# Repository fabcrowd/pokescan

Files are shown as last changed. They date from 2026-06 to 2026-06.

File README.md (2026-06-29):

# Card Scanner Stand — iPhone 16 Pro + Toybox

A **plastic-modular copy stand on a single wood-dowel spine** for scanning trading cards (Pokémon, MTG, sports, etc.) with a phone camera app (Delver, ManaBox, Collectr, etc.). Everything prints and slide-fits together (no screws); one 8 mm wood dowel is the only wood part, and pulling it flat-packs the whole stand.

The design targets two hard constraints that generic MakerWorld/Thingiverse stands ignore:

1. **Toybox Alpha 3 build volume** — **70 × 80 × 90 mm** (script uses conservative **68 × 78 × 88** usable). Large parts **split** with sliding dovetails (sides) + tongue-and-groove (bottom).
2. **iPhone 16 Pro optics** — the main (Fusion) wide camera has a large minimum focus distance and a **focus dead zone**; the LED torch sits on-axis next to the lens and creates **holo/foil glare** unless the light path is shaped.

---

## Current recommended architecture

**Plastic-modular column** on one **8 mm wood dowel** + **adjustable cam-lever phone head** + **rotating cross-polarizer** + **flow-through card lane** (Phase-2 feeder ready). Every part fits the Toybox bed; slide-fit joints, no screws.

| Part | Material | Role |
|---|---|---|
| `base_left/right.stl` | Print ×1 each | Split ballast base (120×72 mm assembled); dovetail + T&G joinery |
| `column_segment.stl` ×3 | Print | 34×34 posts; boss/recess slide-nest; vertical dowel bore |
| `head_post.stl` | Print | Scaled runway + **D-index flat** (rotation key) |
| `head_clamp.stl` | Print | Bilateral split collar; shelf pins + scale pointer |
| `cam_lever.stl` + `clamp_pin.stl` | Print | Flip-down eccentric lever |
| `phone_shelf_left/right.stl` | Print ×1 each | Split shelf (68×68 mm assembled); camera opening toward card |
| `torch_deflector.stl` | Print | Off-axis baffle (**black** PLA) |
| `polarizer_base.stl` + `polarizer_dial.stl` | Print | Rotating lens polarizer (**black** base) |
| `card_lane_left/right.stl` | Print ×1 each | Gravity ramp → flat scan nest; magazine dock rails + latch notch |
| `card_magazine_left/right.stl` | Print ×3 sets | Modular card magazine cartridge halves (snap-in, gravity feed) |
| `card_magazine_lid.stl` | Print ×6 | Snap-on lid per half (keeps stack aligned during transport) |
| `nest_frame.stl` | Print ×1 | Phase-2a scan deck frame with U-channels |
| `nest_tray_ramp.stl` / `nest_tray_bin.stl` | Print ×1 each | Phase-2a slide-out tray halves (butt-join at centre) |
| `nest_stop.stl` | Print ×1 | Phase-2a hard return stop tab |
| 8 mm dowel | Wood (only wood part) | Spine through base → segments → head_post socket |

```
Side view (conceptual)

  ┌─────────────── iPhone 16 Pro (camera down)
  │   [polarizer dial rotates] + torch deflector cartridge
  ╞═══════════════ phone_shelf (on head_clamp pins)
 ┌┴┐ head_clamp ← slides on head_post scale; cam_lever locks
 │ ║ ║ head_post runway (55 mm travel, engraved ticks)
 │ ║ ║
 │ ║ ║ ← 8 mm wood dowel
 │ ║ ║   column_segment ×3
 ┌┴─╨─┴┐ base              card_lane: hopper lip ↘ ramp ↘ scan nest (z0) ↘ bin step
 └─────┘                   [horn slot — Phase-2a gate linkage; see docs/phase-2a-manual-feeder.md]
  Lens 296–331 mm (3 segments, clamp range) — ≥260 mm ✓
  verify_assembly() checks lens XY over scan nest (≤2 mm)
```

---

## CS30 Arch v13 — Integrated Phone Arch + Gravity Ramp (current)

`design/cs30_arch.py` — a **Card Slinger 3.0-inspired arch** that wraps the `photo_box` light enclosure. Five printable parts (black PLA), two M3 bolts, two M3 hex nuts. No wood. No separate mount needed — the arch legs stand on the table with wide foot plates that abut the photo_box walls for lateral location.

```
Side view

  ┌───────────────────────── phone bridge (two halves, camera aperture 36×30mm)
  │    ←  dual sockets snap onto two carriage pegs (x=41mm + x=57mm)
  ╞═══════╤═════╤══════════ carriages lock with M3 knob (5mm rack pitch)
  │       │     │
  │       │     │  arch legs (2 sections each, 82mm+82mm = 164mm)
  │       │     │
  ╞═══════╧═════╧══════════ legs clip to photo_box left/right walls (8mm thick)
  [  photo_box v25 (84×44×44mm, LED-lit, white PLA)  ]
  ← gravity ramp clips to front end cap → cards slide to scan window →
```

### Part list and print settings (v13)

| STL | Qty | Bed dims | Orientation | Profile | Infill | Brim | Notes |
|-----|-----|---|---|---|---|---|---|
| `cs30_fit_test.stl` | 1 | 68×16×30mm | Flat (Z-up) | Recommended | 15% gyroid | None | **Print FIRST** (~18 min); validates (A) carriage-on-leg, (B) bridge peg, (C) ramp C-clip, **(D) M3 bolt/nut trap** |
| `cs30_ramp.stl` | 1 | 68×70.7×32.6mm | Flat (floor down) | Recommended | 15% gyroid | None | 20° gravity ramp; C-clip foot snaps onto photo_box front end cap (3mm); self-supporting |
| `cs30_arch_leg_section.stl` | **4** | **14×24×87mm** | Standing (Z-up, **foot plate down**) | Recommended | 20% gyroid | **NO** | 2 per leg, stack → 164mm; 24mm foot plate is bed face; corner notches clear photo_box end cap; inner face abuts wall; **no brim — 1mm bed margin** |
| `cs30_phone_bridge_half.stl` | **2** | 60×78×10mm | Flat (plate face down) | Better Quality | 20% gyroid | **NO** | 6mm plate; blind carriage sockets (5mm + 1mm floor); butt join at x=0; **no brim — 1mm bed margin** |
| `cs30_arch_carriage.stl` | **2** | 30×16×55mm | +Y face down (C-channel up) | Better Quality | 25% gyroid | ON | Slot 14.6×12.3mm clears rack teeth; nut trap 5.7mm; finer layers improve bore + slot |
| `cs30_lock_knob.stl` | **2** | 19.2×20×8mm | Flat (bottom face down) | Better Quality | 20% gyroid | None | **Top-face** socket (outer face when assembled) captures M3×30mm bolt head; six grip flats; indicator groove on top |

All parts: black PLA. 3 perimeter walls, 0.2mm layers. No supports.

### Hardware (v13)

| Item | Qty | Role |
|---|-----|---|
| M3×**30mm** socket-head bolt (ISO 4762) | 2× | Through carriage ±X; clamps leg — 30mm needed (25mm falls 2mm short of nut) |
| M3 hex nut | 2× | Drops into square nut trap on carriage +X face |

### Fit test procedure

Print `cs30_fit_test.stl` flat. Four features on one 68×16×30mm part:

| Feature | Test | Pass | Fail → adjust |
|---|---|---|---|
| **(A) Leg stub** (left, x=-22) | Slide printed carriage C-channel down over 14×10mm column | Slides freely, ~0.3mm play | `CARR_CL` 0.3→0.4mm, reprint |
| **(B) Peg base** (centre) | Press bridge half sockets over 3mm-radius pegs at ±8mm | Snaps on with light thumb pressure, no wobble | `SEC_PEG_CL` 0.3→0.35mm, reprint |
| **(C) End cap stub** (right, x=+21) | Press ramp C-clip foot over 3mm plate | Snaps with single push, stays held | `EC_SOCK_CL` 0.3→0.4mm, reprint |
| **(D) Nut trap stub** (far right, x=+30..39) | Thread M3×**30mm** bolt through 3.4mm hole; drop M3 hex nut into 5.7×5.7mm pocket | Bolt passes freely; nut drops flush with fingers | Bolt binds → `BOLT_D` 3.4→3.6mm; nut jams → `NUT_TRAP_CL` 0.2→0.35mm; reprint |

### Assembly sequence

See `docs/cs30_assembly.md` for the full 8-step guide. Quick overview:

1. Build photo_box (see `docs/photo_box_assembly.md`)
2. Drop M3 nut into each carriage trap; insert M3×30mm bolt from -X face, thread into nut; slide lock knob onto bolt head
3. Slide one carriage onto each leg section from the top
4. Stack two leg sections per side (male peg → female socket, press flush)
5. Stand each leg stack beside the photo_box left/right walls — foot plate (24mm wide) rests on table; inner x-face of foot abuts photo_box wall outer face for lateral location
6. Slide both carriages to the same rack tooth mark; tighten both knobs
7. Press both bridge halves down onto carriage pegs; halves meet at centreline
8. Snap ramp C-clip foot over photo_box front end cap (3mm body)

### Height adjustment

| Rack mark | Bridge height | Camera → card | Focus mode |
|---|---|---|---|
| 30mm | 85mm | **81mm (8.1cm)** | Ultra-wide macro ✓ |
| 50mm | 105mm | **101mm (10.1cm)** | Ultra-wide macro ✓ |
| 70mm | 125mm | **121mm (12.1cm)** | Ultra-wide macro ✓ **(recommended)** |
| 80mm | 135mm | **131mm (13.1cm)** | Ultra-wide macro ✓ |
| 85mm | 140mm | **136mm (13.6cm)** | Ultra-wide macro ✓ (safe limit) |
| 90mm | 145mm | **141mm (14.1cm)** | Ultra-wide macro (borderline — may switch lens) |
| 95mm | 150mm | **146mm (14.6cm)** | ⚠ Borderline — test before batch scanning |

Camera → card = bridge height − 4mm (card face at FLOOR_T=4mm above table). Bridge height = rack mark + 55mm (CARR_H=50 + SEC_PEG_H=5). Maximum physical rack mark = 114mm (column height 164mm − CARR_H 50mm). Dead zone for iPhone 16 Pro main camera begins around 14cm; ultra-wide macro covers 2cm–14cm.

**Recommended range: rack marks 30–85mm** — keeps camera-to-card under 136mm, safely within ultra-wide macro territory. At rack mark 90mm the camera-to-card distance is 141mm, which is borderline (iOS may auto-switch to the main lens). Rack mark 70mm (≈12cm) gives the best framing balance. Use 2× digital zoom in Apple Camera or Magnifier for tighter crops without moving closer.

Each tooth = 5mm. Loosen both knobs → slide to mark → tighten → recheck level.

> **App compatibility at macro range:** Apple Camera (auto-switches to ultra-wide macro below ~14cm) and Magnifier work at any rack mark. Third-party scanner apps (Delver Lens, ManaBox, Collectr) may stay on the main camera and blur — test at rack mark 50 before committing to a batch scan.

### Clearance reference (v13)

| Interface | Constant | Value |
|---|---|---|
| Carriage C-channel → leg | `CARR_CL` | 0.3mm/face |
| Bridge socket → carriage peg | `SEC_PEG_CL` | 0.3mm radius |
| Ramp C-clip → end cap body | `EC_SOCK_CL` | 0.3mm/face |
| M3 bolt clearance | `BOLT_D` | 3.4mm |

### Rebuild cs30_arch STLs

```bash
# AgentCAD (Claude Code):
#   mcp__agentcad__run("design/cs30_arch.py", "rebuild", params="PART=N")
#   PART=0 = assembly preview  1=ramp  2=leg_section  3=bridge_half  4=carriage  5=lock_knob

# Direct:
uvx --from build123d --with bd_warehouse python design/cs30_arch.py
# Set PART=N at top of script; STLs land in design/output/cs30_*.stl
```

### System verification

After changing any constant in `photo_box.py` or `cs30_arch.py`, run the constraint checker to confirm clearances, optics, and macro focus range are still valid:

```bash
py design/cs30_verify.py
```

19 checks across 6 categories (camera-to-card range, geometric clearances, aperture vignetting, LED channel depth, foot plate notch, bridge alignment). Exits 0 on pass, 1 on failure. Takes under 1 second — no build123d or AgentCAD required.

---

## CS2 — Card Scanner v2 (C-Stand + Hopper, Toybox-native)

`design/cs2_*.py` — a **Card Slinger 2-inspired vertical platform stand** with an open-top card hopper and a height-adjustable phone shelf. All parts fit the Toybox bed without modification. No wood. No arch structure. Card drops in face-up; phone rests on shelf above looking down through a 36×30 mm aperture.

```
Side view

  ┌──────────────────────────────────── iPhone 16 Pro (face down)
  │   camera aperture: 36×30mm
  ╞══════════════════════════════════ platform (68×75×8mm, adjustable)
  │                                    bolts to wall at 4 heights: 100/125/150/165mm
  │  ┌─────────────────────────┐
  │  │   wall column           │  97×14×174mm (2 sections × 2 halves)
  │  │   (black PLA, upright)  │
  │  └─────────────────────────┘
  [  hopper (97×72×50mm, 2 halves)  ]
     open-top card slot: 90×65mm
     card face at z=4mm (FLOOR_T)
```

### Part list (all black PLA unless noted)

| STL | Dims (mm) | Qty | Orientation | Notes |
|-----|---|-----|---|---|
| **`cs2_fit_test.stl`** | 64×38×20 | 1 | Flat | **Print FIRST** — validates peg fit + pol_clip aperture press-fit |
| `cs2_hopper_left.stl` | 48.5×72×70 | 1 | Upright | Left half of card hopper (v3, 70mm, ~160 cards); Phase 2 shaft holes + exit slot |
| `cs2_hopper_right.stl` | 48.5×72×70 | 1 | Upright | Right half |
| `cs2_platform.stl` | 68×75×8 | 1 | Flat | Phone shelf; Y-direction M3 bolt holes at x=±22mm |
| `cs2_wall_bot_left.stl` | 49.5×20×88 | 1 | Upright | Bottom-left wall section |
| `cs2_wall_bot_right.stl` | 49.5×20×88 | 1 | Upright | Bottom-right wall section |
| `cs2_wall_top_left.stl` | 49.5×14×88 | 1 | Upright | Top-left wall section |
| `cs2_wall_top_right.stl` | 49.5×14×88 | 1 | Upright | Top-right wall section |
| `cs2_peg.stl` | 10×10×10 | 1 plate | Flat | 4× 3mm alignment pegs; use 2 for hopper join (PETG preferred) |
| `cs2_pol_clip.stl` | 44×38×8 | 1 | Flat | **White PLA** — optional; polarizer film clip for aperture |
| `cs2_phone_pol.stl` | 44×38×3 | 1 | Flat | **White PLA** — optional; matched phone-camera polarizer frame |
| `cs2_diffuser.stl` | 68×75×1.5 | 1 | Flat + **brim** | **White PLA** — optional; torch scatter plate for diffuse fill light |

All parts: 3 perimeter walls, 0.2mm layers, 20% infill, no supports.

### Hardware BOM (per scanner)

| Item | Qty | Spec | Use |
|---|-----|---|-----|
| M3×30mm socket-head bolt | 8 | ISO 4762 | Platform-to-wall (2) + wall section joins (6) |
| M3×20mm socket-head bolt | 6 | ISO 4762 | Hopper half joins (2) + spare |
| M3 hex nut | 14 | standard | All bolt receivers |
| 3mm dowel pin | 2 | from `cs2_peg.stl` | Hopper seam alignment |
| CA glue | small tube | cyanoacrylate | Wall flange to hopper back face (Phase 1) |

### Fit test procedure

Print `cs2_fit_test.stl` flat — same PLA colour as target parts (pigment affects shrink).

| Feature | Test | Pass | Fail → adjust |
|---|---|---|---|
| **(A) Hole block** (left, x=−22) | Insert 3mm dowel (cut from `cs2_peg.stl`) into blind hole at z=14mm; thread M3×20mm bolt through at z=8mm | Dowel slides in with light thumb push; bolt passes freely | Dowel too tight → `PEG_D` in `cs2_peg.py` +0.05mm steps; reprint peg plate |
| **(B) Aperture ring** (right, x=+20) | Press `cs2_pol_clip` plug (35.6×29.6mm) into the 36×30mm opening from below | Firms up with thumb pressure; stays without adhesive | Too tight → `PLUG_W`/`PLUG_D` in `cs2_pol_clip.py` +0.1mm; too loose → −0.1mm; reprint clip |

### Assembly sequence

See **`docs/cs2_assembly.md`** for the full step-by-step guide including fit test procedure, accessory setup, and iPhone placement notes.

Quick reference:
1. **Join hopper halves:** align seam at x=0; insert 2× 3mm dowel pegs (front + back, z=17mm); thread 2× M3×20mm bolts at z=25mm.
2. **Build wall column:** join 4 sections into bot + top pairs (3× M3×30mm per seam); join left+right sides.
3. **Attach wall to hopper:** CA glue wall front face to hopper back face; hold 60 s.
4. **Mount platform:** M3×30mm bolts through platform back edge (Y-direction, x=±22mm, z=4mm from bottom); thread into wall; nut on wall back face.
5. **Scan:** card face-up in hopper; phone face-down on platform, camera over aperture.

> **Workflow speed:** drop a full load (≈120 cards, or ≈160 with the 70mm tall v3 hopper) through the centering insert (`cs2_centering_insert.stl`) — cards self-align in under a second. Scan + manual eject: ~900 cards/hour. With Phase-2 motorised eject and separator: ~600–900 cards/hour realistic. See `docs/workflow-speed.md` for the full capacity table and toss-and-scan steps.

### Height settings

| Platform position (mm) | Camera→card clearance | Notes |
|---|---|---|
| 100 | 104mm (10.4cm) | Ultra-wide macro ✓ |
| 125 | 129mm (12.9cm) | Ultra-wide macro ✓ **(recommended)** |
| 150 | 154mm (15.4cm) | Borderline macro — test before batch |
| 165 | 169mm (16.9cm) | Main camera territory |

Camera→card = platform Z + PLAT_T(8) − FLOOR_T(4). Ultra-wide macro range: 2cm–14cm.

### Lighting accessories (optional)

**Diffuser plate** (`cs2_diffuser.stl` — white PLA, 68×75×1.5mm): Lay flat on the platform top; phone rests on the diffuser. The phone torch hits the white PLA surface and scatters sideways into the hopper, converting the harsh point-source torch into broad soft-box fill light. The 36×30mm aperture cut-out aligns with the platform aperture exactly. Use brim in slicer — 1.5mm thin part at 68mm bed width warps without it.

**Cross-polarization** (`cs2_pol_clip.stl` + `cs2_phone_pol.stl` — holographic/foil cards only): Print both in white PLA. Cut two 30×24mm squares from a linear polarizing film sheet. Insert one square into each clip's recess. Rotate one square 90° relative to the other. Slip `cs2_pol_clip` into the platform aperture from below; hold `cs2_phone_pol` over the phone camera with a rubber band through the 4 corner holes. Kills specular glare on holo/foil surfaces.

**Recommended combinations:**
- Standard cards: diffuser plate only
- Holo/foil cards: diffuser plate + cross-pol pair

### Rebuild CS2 STLs

```bash
# Set PART=N at top of each script, then run via AgentCAD or directly:
uvx --from build123d python design/cs2_hopper.py   # PART=1 left / PART=2 right
uvx --from build123d python design/cs2_wall.py     # PART=1..4 for four sections
uvx --from build123d python design/cs2_platform.py # PART=0 single piece
```

### Verify CS2 geometry

```bash
py design/cs2_verify.py
```

31 checks: bed fit, card clearance, aperture alignment, platform height range, shaft hole clearance, wall coverage, bolt alignment, peg clearance. Exits 0 on pass.

---

## v2: Rack-Pinion Adjustable Stand *(superseded by CS30 Arch v5)*

`design/rack_stand_v2.py` — a **Card Slinger-inspired** stand with a rack-and-pinion height adjustment column. Eight printable parts (including one tolerance test block), two M3 bolts, and a rubber band. No wood required.

```
Card flow + camera geometry

  y = 0 mm  ← user inserts card here (tray_back funnel entry)
  y = 44 mm ← camera aims here  (card centre; tray split join)
  y = 88 mm ← back of tray / stand column base (STAND_Y = CARD_L)

  z-stack (lowest carriage position = 260 mm lens height):
    z=0        table
    z=0..13.5  card tray (tray_back y=0..44, tray_front y=44..88)
    z=13.5     foot bottom rests on tray wall tops (x = ±32..35 mm)
    z=13.5..45.5  stand foot body (70×50×32 mm)
    z=45.5..49.5  foot D-peg → rack section 1 socket
    z=45.5..285.5 rack column (3 × 80 mm sections)
    z=205.5+   phone carriage (section 3 minimum; slides on column, locked with M3 side-bolt)
    z=+CAR_H   phone platform (bolted to carriage with 2× M3×8)
    260..290 mm  lens height range (carriage adjustable within section 3) ✓
```

### Part list and print settings (v2)

| STL | Bed dims | Orientation | Profile | Infill | Qty | Notes |
|-----|---|---|---|---|-----|---|
| `rs2_fit_test.stl` | 42×38×20 mm | Flat (base down) | Recommended | 15% | 1× | **Print FIRST** (with knob) — verify all 5 features before main set |
| `rs2_rack_section.stl` | 26×26×84 mm | Standing (Z-up, teeth on +Y face) | **Better Quality** | 25% | 3× | Finer layers give cleaner tooth faces |
| `rs2_stand_foot.stl` | 70×50×36 mm | **Rotate 90° in slicer** — 70 mm along Y | Recommended | 15% | 1× | 70 mm > 68 mm bed X; rotate to 50×70; 4× dimples on base align with tray wall tops for rubber feet |
| `rs2_tray_front.stl` | 70×50×13.5 mm | **Rotate 90° in slicer** | Recommended | 15% | 1× | Collection half (y=44..88); card-stop tab at y=86..88 mm; **tapered funnel** at join face (y=44) guides cards across seam |
| `rs2_tray_back.stl` | 70×44×13.5 mm | **Rotate 90° in slicer** | Recommended | 15% | 1× | Entry half (y=0..44); **tapered funnel** at user entry (y=0): 68 mm wide → 64 mm over 10 mm, ≈11° per side |
| `rs2_phone_carriage.stl` | 37×47×50 mm | Flat (bore opening up) | **Better Quality** | 25% | 1× | Higher infill for cantilever load; finer layers improve bore roundness |
| `rs2_phone_platform.stl` | 65×75×25 mm | Face-down (pegs/lips point up, no supports) | Recommended | 20% | 1× | M3 countersink pockets on top face |
| `rs2_pinion_knob.stl` | 30×30×42 mm | Standing (disc at top) | **Better Quality** | 25% | 1× | Finer layers on gear teeth and grip grooves |

All parts: 3 perimeter walls, 4 top/bottom layers, **brim** (Toybox has no heated bed). No supports needed for any part in the listed orientation.

### Hardware (v2)

| Item | Qty | Role |
|---|-----|---|
| M3×8 mm socket-head bolt | 2× | Platform → carriage (side-wing pilot holes at x=±16.5 mm) |
| M3×6 mm **button-head** bolt (ISO 7380) | 1× | Carriage lock (self-taps into -X wall; **use 6 mm button-head only** — gives 3.3 mm engagement; longer or socket-head bolts damage rail) |
| Standard rubber band | 1–2× | Cross-hook over 4 pegs (2 front + 2 back lip) — 1 band looped or 2 bands in X-pattern for firm phone retention |
| Stick-on rubber feet (8–10 mm dia, ~1 mm thick) | 8× | Press into tray bottom recesses (4 per half) — prevent stand sliding on desk |
| Stick-on rubber pads (4–6 mm dia, ~1 mm thick) | 4× | **Optional:** press into foot base dimples (x=±33 mm) — improves foot-to-tray grip; can substitute hot glue or leave empty |

### Step 1 — Fit test (print before anything else)

Print `rs2_fit_test.stl` **and** `rs2_pinion_knob.stl` together (~40 min total, 15%/25% infill). Test each feature:

| Feature | How to test | Pass | Fail → fix |
|---|---|---|---|
| **Rail bore pocket** (top, 12 mm deep) | Slide rack section into pocket from top | Moves freely with ~0.3 mm play | Adjust `CAR_CL` ±0.1 mm |
| **D-peg socket** (bottom) | Press stand foot D-peg upward into socket | Snug, needs thumb pressure | Adjust `PEG_CL` ±0.1 mm |
| **Tray peg socket** (+X face, 6 mm deep) | Insert tray_front horizontal peg | Snug fit, pulls out with effort | Adjust `TRAY_PEG_CL` ±0.1 mm |
| **Lock bolt pocket** (-X face, z=4 mm) | Thread M3×6 mm button-head (ISO 7380) from -X face | Head sits flush in recess; shank threads in smoothly | If splits PLA: bore too small (M3 self-tap limit); try slow insertion |
| **Rack stub** (+Y face, 3 teeth) | Press printed pinion_knob hub tangentially; rotate | Teeth slip into gaps freely, no binding | Adjust `GAP_W` from 2.4 → 2.6 mm, reprint knob only |

After adjusting a constant: re-run AgentCAD (or `uvx --from build123d --with bd_warehouse python design/rack_stand_v2.py` — see **Rebuild v2 STLs** below), reprint **only the fit_test** until it passes, then print the full set.

### Step 2 — Assembly sequence (v2)

1. **Join tray halves** — insert tray_front horizontal pegs into tray_back sockets at the y=44 mm join face. Press together. The **tray_back** piece has the user-entry funnel (wider opening, 68 mm); this end faces toward you when scanning.
2. **Set tray on table** — card channel (64 mm wide, centered) faces up. The **wider funnel opening** on tray_back faces toward you; the card stop tab inside tray_front faces away (toward the stand).
3. **Place stand foot** — center foot (70×50 mm base) over back of tray (y=88 mm). Foot bridges the card channel, resting on both tray wall tops (3 mm contact each side).
4. **Stack rack sections** — lower section 1 D-socket (bottom) onto foot D-peg (top). Lower section 2 D-socket onto section 1 D-peg. Lower section 3 D-socket onto section 2 D-peg. Each section's **D-socket is at the bottom**; each section's **D-peg is at the top** for the next. Column is 240 mm tall with teeth on +Y (card) face.
5. **Slide carriage** — lower phone carriage over column from the top. The 4 mm bore lead-in at the carriage top helps align the rail; guide the teeth (+Y face) into the bore slot and lower until the pinion zone passes the rack top.
6. **Insert pinion knob** — slide hub into carriage +X pinion bore; rotate to mesh with rack teeth. Knob disc sits flush with carriage +X face.
7. **Adjust height** — turn pinion knob to move carriage up/down. Target lens range: 260–290 mm above card. Read the rack tick mark nearest the carriage-top notch on the +X face — **the four useful ticks on the top (section 3) segment correspond to: 50 mm → 260 mm lens, 60 mm → 270 mm, 70 mm → 280 mm, 80 mm → 290 mm** (ticks are 10 mm apart; 260 mm is the minimum focus-safe height). Tighten M3×6 **button-head** lock bolt (self-tap into -X carriage wall) finger-tight.
8. **Mount platform** — lower phone platform onto carriage top; align M3 clearance holes (x=±16.5 mm, y=0) over carriage side-wing pilot holes. Thread 2× M3×8 bolts from above.
9. **Place phone** — lay iPhone 16 Pro **camera-side down** (back of phone on platform, screen faces up), camera-cluster end toward -Y (card). Camera opening (36×30 mm) exposes the camera cluster through the platform floor. Front lip retains camera end, rear lip retains back.
10. **Insert card** — slide card (unsleeved, 63 mm wide) into the tray funnel short-edge first, camera-side up. Push until you feel resistance from the card stop. **Fully seated: ~2 mm of the card's trailing edge protrudes from the entry funnel** — this is expected and makes removal easy.
11. **Secure phone** — cross-hook rubber band: front-left peg → diagonally to back-right peg; second band front-right → back-left. Or loop single band front-peg to front-peg over phone back.

> **Break-in tip:** apply a thin smear of white lithium grease or petroleum jelly to the rack teeth (+Y face of the column) before first use. FDM PLA rack-and-pinion benefits from lubrication; friction drops noticeably after 10–20 adjustments.

> **Holo/foil glare tip:** Most scanning apps (ManaBox, Delver Lens, Collectr) use ambient light — they do not fire the torch. Scan in bright room light with no overhead point source directly above the card. For stubborn holos: (1) slightly tilt the whole stand 5–10° forward, or (2) rotate the card 15–30° in the tray before re-scanning. No cross-polarizer is needed for the v2 face-down configuration.

### Clearance reference (v2)

| Interface | Constant | Value | Notes |
|---|---|---|---|
| Rail bore → carriage | `CAR_CL` | 0.6 mm | 0.3 mm/face; generous for Toybox FDM |
| D-peg → socket | `PEG_CL` | 0.35 mm | Radius clearance |
| Tray peg → socket | `TRAY_PEG_CL` | 0.25 mm | Radius clearance |
| Rack tooth → gap | `GAP_W - TOOTH_W` | 0.4 mm | 0.2 mm/side; FDM rack best practice |
| Pinion hub → bore | `CAR_CL` | 0.6 mm | Same as rail |
| Card channel width | `CARD_CL` | 0.5 mm/side | 64 mm channel (63 mm card + 0.5 mm/side); unsleeved card slides freely |
| Tray entry funnel | `FUNNEL_EXTRA` | 2 mm/side | 68 mm wide at y=0 → 64 mm over 10 mm depth; ≈11° per side; self-centering guide at both tray entry faces |

### Rebuild v2 STLs

```bash
# Run with AgentCAD (Claude Code / Cursor with .mcp.json):
mcp__agentcad__run("design/rack_stand_v2.py", "rebuild", render="iso")

# Or run directly with uvx (no venv install needed):
uvx --from build123d --with bd_warehouse python design/rack_stand_v2.py
# STLs land in: design/output/rs2_*.stl
```

Verify: all 8 STLs export, console prints `Lens height range: 260..290 mm  (target >= 260 mm at min)` and `Section H: 84.0 mm`.

---

## Photo Box (pb_*) — diffuse lighting accessory

A white-walled side-lit enclosure for scanning difficult cards — holos, foils, shimmer patterns — where ambient-light scanning produces specular hotspots. The phone looks straight down through the open top. Four 5V LED strip segments (one per wall half) seated in wall channels at z=33.6–44mm provide 44° side illumination that bounces off the white interior to eliminate most glare without a cross-polarizer. The 6mm-deep LED channel gives a 3.2mm diffuser air gap — above the 3mm photography minimum for even illumination. Eight adhesive bumpon feet (3M SJ5302) press into recesses on the platen underside for anti-slide grip. End caps include a 5×8mm LED cable exit slot at the top-inner corner for clean wire routing.

Requires an overhead phone mount at 263mm above the desk. See `docs/photo_box_assembly.md` for the full step-by-step assembly manual. All structural parts: white/coconut matte PLA. Diffuser strip: clear or natural white PLA.

> **Note:** `rack_stand_v2` is **not compatible** — the end caps (x=±43mm wide) physically collide with its foot (x=±35mm) at y=88mm, and moving the foot clear of the end caps shifts the camera 47mm off the card centre.

### Parts list (v24)

| STL | Qty | Bed dims | Notes |
|-----|-----|---|---|
| `pb_platen_back.stl` | 1 | 68×49×6mm | Entry half; 2 near registration nubs; 4 Ø8.5mm bumpon recesses on underside; 0.8mm centreline alignment groove |
| `pb_platen_front.stl` | 1 | 68×44×6mm | Far half; 1 left-far nub + 2mm finger-lift notch; 4 bumpon recesses on underside; 0.8mm centreline alignment groove |
| `pb_wall_half.stl` | **4** | 13.5×44×44mm | 2 per side; LED channel at top (z=33.6..44mm, 6mm deep, 3.2mm diffuser air gap); retention pegs on inner face; end cap sockets at both y-end faces |
| `pb_endcap_half.stl` | **4** | 46×5×44mm | 2 per y-face; chamfered 3mm peg for retention; 5×8mm LED cable exit slot at top-inner corner |
| `pb_led_diffuser.stl` | **4** | 43.6×10.0×0.8mm | Optional — slides in front of LED strip; softens hotspots |
| `pb_fit_test.stl` | **2** | 44×25×4mm | **Print before full set** — validates TAB_CL, PEG_CL, EC_SOCK_CL (~8 min each) |
| `pb_led_channel_test.stl` | **1** | 8×20×14.4mm | Print before wall_half — validates LED strip + diffuser channel fit (~3 min) |
| `pb_card_tray.stl` | 1 | 68×27×37mm | Optional deck holder for batch scanning; holds ~80 unsleeved cards; 15° gravity-assist ramp self-presents cards (6.7mm wedge floor at back) |

**10 structural pieces + 4 optional diffuser strips. Print fit_test × 2 and led_channel_test × 1 first.**

**Hardware:** 3M SJ5302 clear bumpons Ø7.9mm (8 required); 5V 10mm LED strip cut to 4 × 44mm segments; 5V USB power supply ≥1A.

### Print settings

| Part | Profile | Orientation | Infill | Brim |
|---|---|---|---|---|
| `pb_fit_test` | Recommended | **Flat (4mm tall)** — print 2× first | 15% gyroid | None |
| `pb_platen_back` | Recommended | **68mm in slicer Y** (not X) — flat (6mm tall); 68+3+3=74mm fits Y=78mm | 15% gyroid | 3mm |
| `pb_platen_front` | Recommended | **68mm in slicer Y** (not X) — flat (6mm tall); same orientation as back | 15% gyroid | 3mm |
| `pb_wall_half` | Recommended | **Standing** — outer face (stability foot) **down**, 13.5×44mm base, 44mm tall | 15% gyroid | ON |
| `pb_endcap_half` | Recommended | Flat on 46×44mm XZ face → **5mm tall** (body 3mm + peg 2mm) | 15% gyroid | None |
| `pb_led_diffuser` | Recommended | **Flat** (0.8mm tall = 4 layers); clear/natural PLA | 100% rectilinear | None |
| `pb_led_channel_test` | Any colour | Flat on 8×20mm face, 14.4mm tall — print before wall_half | 15% gyroid | None |
| `pb_card_tray` | Any colour | **68mm in slicer Y** — flat (37mm tall), no brim needed | 15% gyroid | None |

3 perimeter walls, 0.2mm layers. No supports.

### Assembly

See `docs/photo_box_assembly.md` for the full illustrated step-by-step manual with fit-test procedure, orientation guide, tolerance diagnosis, and disassembly.

**Quick sequence:**

1. **Join platen halves** — back half (2 nubs) toward you; press tabs into slots at y=44mm seam.
2. **Install bumpons** — flip platen over; press one 3M SJ5302 bumpon into each of the 8 Ø8.5mm recesses (4 per half). Flip right-side-up.
3. **Seat walls** — hold each wall half inner-face toward platen long edge, foot outward; slide straight **down** so pegs enter platen side-face slots. Repeat for all 4 halves (2 per side).
4. **Attach end caps** — **back end caps** (nub end): install with chamfered peg facing +Y into wall socket. **Front end caps** (notch end): flip each cap 180° around Z, then install peg facing −Y into wall socket. Rule: peg always faces INTO the box.
5. **Insert LED strips** — press a 44mm segment of 10mm-wide 5V adhesive strip into each wall's inner-face channel (10.4mm wide × 6mm deep, 0.2mm/side clearance). Route connector wire through the end cap cable exit slot. Optional: slide `pb_led_diffuser` strip in front to soften hotspots — the 3.2mm air gap provides photography-grade diffusion.

### LED strip spec

| Spec | Value |
|---|---|
| Width | 10mm (standard 5V USB cut-to-length) |
| Colour | Warm white 3000–4000K for accurate card colour |
| Qty | **4 segments × 44mm** (one per wall half); ~176mm total strip length |
| Power | USB 5V **≥1A** minimum; ~40–60mA/segment × 4 = 160–240mA typical; wire in **parallel** only |
| Wire routing | Through end cap cable exit slot (5×8mm, top-inner corner) |

### Phone mount

The photo box requires an **overhead phone mount** at **263mm above the desk** (259mm above card face at z=4mm). At that distance the iPhone 16 Pro 24mm camera covers ~106×79mm — the 63×88mm card fits in frame in both portrait and landscape phone orientations. Recommended options:

| Type | Notes |
|---|---|
| Desk gooseneck clamp (Tryone, Lamicall, SAIJI) | ~$15–25, 85cm arm, desk-edge clamp — most versatile |
| Arkon RoadVise 12" rigid gooseneck | 305mm reach, C-clamp — good for fixed setups |
| Overhead copy stand boom arm | Most stable for high-volume scanning |

Setup: clamp arm to desk edge; bend gooseneck to put phone face-down at 263mm, centred over the box. The box can sit 50–100mm from the desk edge; an 85cm arm reaches easily.

> **Why not rack_stand_v2?** The foot (70mm wide, x=±35mm) collides with the end caps (88mm wide, x=±44mm) when placed at y=88mm. Sliding the foot back clears the collision but shifts the camera off-axis beyond acceptable parallax. Use a separate mount for the photo box.

### Usage

1. Place photo box on desk, open top up.
2. Mount phone overhead at **263mm** lens height. With no card in the box, use the **0.8mm centreline groove** (visible as a dark hairline on the white platen) to centre the viewfinder left/right, then lock the arm.
3. Place card **face-up** on platen. Push near edge against the two near nubs (Y-stop), then push left edge against the left nubs (X-stop).
4. Right-far corner is open; a **2.5mm deep finger-lift notch** (2.2mm gap under card corner) helps slide a finger under the card for removal.
5. Power on LED strips. Scan.

**Card registration — 3-corner kinematic:**

```
  left-near nub ──┐     right-near nub ──┐
  (Y + X stop)    │     (Y stop)          │
  ┌───────────────┼───────────────────────┤
  │  card 63×88mm                         │
  │                                       │
  └───────────────────────────────── open ┘
  left-far nub (X stop)    right-far: OPEN + finger-lift notch
```

Push card into the near-left corner → 3 nubs constrain x, y, and rotation. Right-far corner stays open for lift-out.

### Rebuild photo box STLs

```bash
uvx --from build123d --with bd_warehouse python design/photo_box.py
# STLs land in design/output/pb_*.stl
# Individual part: AgentCAD params="PART=N"
#   1=platen_back  2=platen_front  3=wall_half  4=endcap_half  5=led_diffuser  6=fit_test  7=led_channel_test
```

---

## iPhone 16 Pro — focus distance (read this first)

These numbers drive **how tall the stand must be**. Getting this wrong produces blur or lens switching jitter.

| Distance (lens → card) | What happens |
|---|---|
| **< ~14 cm** | iOS switches to **ultra-wide macro**; viewfinder can jitter between wide and macro. Works in Apple Camera / Magnifier; **some third-party scanners stay on wide and blur**. |
| **~14–25 cm** | **Dead zone** — main wide camera often **cannot lock focus**. Avoid this range. |
| **≥ ~26 cm** | **Main Fusion camera focuses reliably** in essentially any scanning app. Card occupies ~30% of frame height; use **2×** in Camera or in-app zoom for tighter framing without moving closer. |

**Design choice for this repo:** lens-to-card ≥ **260 mm**. With **3 segments**, lowest clamp ≈ **296 mm**; highest ≈ **331 mm** (nested joint stack accounted). `SEGMENT_COUNT` is the coarse knob.

### Compact alternative (not the default)

If you only scan in apps that honor ultra-wide macro (Apple Camera, Magnifier), you can build a **~10–11 cm** stand. Shorter and more stable, but **not reliable for all scanner apps**. Document any compact variant separately before regenerating geometry.

---

## Glare and torch lighting (holo / foil cards)

The phone torch sits **on-axis beside the lens** — the worst geometry for holo specular hotspots. This build uses three layers:

| Layer | What it does | Part |
|---|---|---|
| **Off-axis + diffuse torch** | Baffle blocks direct torch→card ray; angled face + diffuser slot skim light ≥30° off-axis | `torch_deflector` |
| **Cross-polarization** | Linear film over torch (fixed) + over lens (**rotate dial** until glare nulls ~90° crossed) | `polarizer_base` + `polarizer_dial` |
| **Matte black in light path** | Absorbs stray scatter (white/glossy baffles reintroduce flare) | Print deflector + base in **black** |

**Workflow:**

1. Start with **`torch_deflector`** only; medium torch brightness.
2. If holos still clip, swap to **`polarizer_base`** + insert film; snap on **`polarizer_dial`**.
3. **Rotate the dial** while watching the preview until the holo hotspot disappears (expect ~1–3 stops less light — raise torch slightly).
4. Under **diffuse room light** (no torch), the dial still helps; deflector is optional.

**Also helps:** lens mask (black ring around window), plain white scan surfaces, card flat on lane.

### Drop-in cartridges (same seat on `phone_shelf`)

Both cartridges share one **3 mm rabbet** around the camera opening. Swap without reprinting the shelf.

1. **`torch_deflector`** — default; taller baffle, angled torch face, diffuser pocket for translucent insert.
2. **`polarizer_base` + `polarizer_dial`** — best glare kill; needs ~$10 linear polarizer film (two small squares: torch + lens).

---

## Set the height / zoom

Fine-tune lens-to-card distance with the **head clamp** on the post scale (coarse height = segment count).

| Scale tick (mm) | Lens → card (mm) |
|---|---|
| 0 | ~296 |
| 5 | ~301 |
| 10 | ~306 |
| 15 | ~311 |
| 20 | ~316 |
| 25 | ~321 |
| 30 | ~326 |
| 35 | ~331 |

**How to set:** slide `head_clamp` to the tick that gives the framing you want → flip **`cam_lever`** down to lock → drop shelf on pins.

Re-run `py build_woodstand.py` after changing `SEGMENT_COUNT`; the script prints an updated table.

> **Print-and-tune:** The script verifies geometry only. Cam clamp force and dial friction depend on `POST_CL`, `CAM_ECC`, and `DIAL_CL` — expect one test print and light sanding per the slide-fit convention.

---

## Hardware reference

### Toybox Alpha 3 printer

| Spec | Value |
|---|---|
| Build volume | **70 × 80 × 90 mm** (script usable **68 × 78 × 88**) |
| Filament | **1.75 mm PLA** — Toybox "Printer Food" **or third-party PLA** (both allowed) |
| Heated bed | **No** — use **brim** on large flat parts (mandatory) |
| Nozzle | 0.4 mm; quality **profile** sets layer height + speed |
| Slicer | Creator Space — **infill density**, **infill pattern**, adhesion (**none / skirt / brim**), supports (**none / basic / tree**) |

**Your spools:** **coconut** = official Toybox white; black/yellow/red/blue/teal/purple are likely third-party matte PLA — all fine.

**Two-color split:** coconut/white scan surfaces; **black** torch deflector + polarizer base.

**Profiles available in Creator Space:** Draft (skip) → **Recommended** (~0.2 mm) → **Better Quality** (~0.15 mm) → **Best Quality** (~0.1 mm). You can also set **infill density**, **infill pattern**, **adhesion**, and **support type** per print — see `output/PRINT-MANIFEST.md` for every STL.

---

### Print process (follow for every part)

Every STL must pass all seven steps before it is considered done. Do not skip steps on reprints.

1. **Generate** — run `py build_woodstand.py`; confirm the part prints `[OK]` + `watertight=True` and `verify_assembly()` passes.
2. **Preview** — run `py scripts/preview_stl.py output/<part>.stl`; confirm shape and bbox look right (AI iteration step — see [3DPrintedDecor guide](https://3dprinteddecor.com/how-to-use-claude-for-3d-printing/)).
3. **Import** — open Creator Space → *Create → Import STL* → select the file from `output/`.
4. **Orient** — rotate to the orientation in the table below. Do not let Creator Space auto-orient.
5. **Configure** — set Profile, **infill density**, **infill pattern**, **adhesion**, and **supports** from `output/PRINT-MANIFEST.md`. Check the slicer preview for overhangs before accepting.
6. **Print** — send to printer. Do not change filament mid-print.
7. **Tune and record** — test fit the part in assembly. If a slide fit is tight, sand and record the confirmed clearance (e.g. `POST_CL`, `DIAL_CL`, `CAM_ECC`) in the **Tuning log** below. Update `build_woodstand.py` and this README immediately.

> **Maintenance rule:** any time a parameter in `build_woodstand.py` is physically confirmed or corrected after a test print, update both the parameter value in the script *and* the tuning log in this section. The README is the living manual — it must stay in sync with what actually prints.

---

### Per-part settings

| Part | Profile | Brim | Supports | Filament | Orientation |
|---|---|---|---|---|---|
| `base_left` / `base_right` | **Recommended** | **ON** | None | Coconut/white | Flat (Z-up) |
| `column_segment` ×3 | **Recommended** | **ON** | None | Any matte | **Vertical, boss down** |
| `head_post` | **Better Quality** | **ON** | None | Any matte | **Vertical, boss down** |
| `head_clamp` | **Better Quality** | **ON** | Basic (ears only if slicer flags) | Any matte | Bore vertical, collar flat |
| `cam_lever` | **Better Quality** | None | None | Any matte | Flat, handle extending |
| `clamp_pin` | **Better Quality** | None | None | Any matte | Upright, head down |
| `phone_shelf_left` / `phone_shelf_right` | **Recommended** | **ON** | None | Coconut/white | Flat |
| `torch_deflector` | **Better Quality** | **ON** | None | **Black** | Flat, baffles up |
| `polarizer_base` | **Better Quality** | **ON** | None | **Black** | Flat |
| `polarizer_dial` | **Best Quality** | **ON (wide brim)** | None | Black | Flat, disc face up |
| `card_lane_left` / `card_lane_right` | **Recommended** | **ON** | Check ramp in preview | Coconut/white | Flat, ramp up |
| `card_magazine_left` / `card_magazine_right` | **Recommended** | **ON** | None (vertical walls self-support) | Coconut/white | Join face down, open top up |
| `card_magazine_lid` | **Recommended** | None | None | Any | Flat (lid face down) |
| `nest_frame` | **Recommended** | **ON** | None | Coconut/white | Flat, channels up |
| `nest_tray_ramp` / `nest_tray_bin` | **Recommended** | **ON** | None | Coconut/white | Flat, deck face up |
| `nest_stop` | **Recommended** | None | None | Coconut/white | Flat |

**Infill density, infill pattern, adhesion (none/skirt/brim), and support type (none/basic/tree)** for every STL: [`output/PRINT-MANIFEST.md`](output/PRINT-MANIFEST.md) (includes Pokémon color column).

**Slicer notes:**
- Set **infill density and pattern explicitly** in Creator Space — profile alone is not enough.
- `polarizer_dial` (2.2 mm disc): use the widest brim Creator Space allows; print solo.
- `head_clamp` axle holes bridge ~8 mm — check preview; Basic supports only if slicer flags drooping (not Tree — too hard to remove from a small bore).
- `card_lane_*` ramp is a stepped staircase (self-supporting); Tree supports only if Creator Space flags the ramp underside.
- `clamp_pin` alternative: cut a 26 mm section of the 8 mm dowel — stronger, zero fit issue.

---

### Tuning log

Record confirmed clearance values here after physical test prints. These feed back into `build_woodstand.py`.

| Parameter | Script default | Confirmed value | Part | Notes |
|---|---|---|---|---|
| `POST_CL` | 0.4 mm | — | `head_clamp` bore on `head_post` | Sand runway −x face if clamp binds |
| `CAM_ECC` | 2.5 mm | — | `cam_lever` | Increase if lever doesn't lock over-center |
| `DIAL_CL` | 0.1 mm | — | `polarizer_dial` in `polarizer_base` race | Increase if dial won't snap in; decrease if it rattles |
| `JOIN_CLEAR` | 0.25 mm | — | All dovetail / T&G joints | Sand dovetail if halves won't slide |

_Last tuned: not yet printed._

### iPhone 16 Pro (rear)

| Spec | Approx. value |
|---|---|
| Body | 149.6 × 71.5 × 8.25 mm, ~199 g |
| Main camera | 48 MP Fusion, 24 mm equiv., f/1.78 |
| Macro | Ultra-wide auto-macro below ~14 cm |
| Torch | Dual LED, adjacent to camera cluster (top-left on back) |

Phone sits **screen-up** on the shelf; **camera bump over the opening**; body lies **back over the column** so only the lens end cantilevers forward (~30–40 mm) over the card.

### Standard trading card

**63 × 88 mm** raw **unsleeved** (Pokémon / MTG / most TCG). Sleeves add glare and bow — lane and future feeder are sized for raw cards. Adjust in `build_woodstand.py` only if you deliberately scan sleeved cards.

---

## Phase-2 card magazine (implemented)

A **gun-magazine style** preloaded cartridge that snaps onto the left face of `card_lane_left`. Load a stack of cards off the scanner, snap the magazine on, scan until empty, pop it off and swap the next — ~3 seconds to reload.

### How it works

```
  Load cards (top open)
       ↓
  [card_magazine_left + card_magazine_right assembled]
       |  cards stacked face-to-face in Z (up to ~128 cards)
       |  bottom card rests at Z = 22 mm (hopper floor)
       ↓
  Dock gesture: hold magazine above lane left face → push DOWN →
                spring tab cams over ledge → CLICK — seated
  Release:      thumb presses spring tab → lift straight UP
```

### Magazine dock features on `card_lane_left`

- **Guide rails** — two 3×6 mm rectangular protrusions on the left face (front and back of lane), spanning full hopper height. Magazine guide slots slide over them.
- **Latch notch** — 4 mm deep × 6 mm wide pocket centred in Y; the magazine spring tab snaps in.

### Magazine cartridge parts

| Part | Qty to print | Notes |
|---|---|---|
| `card_magazine_left.stl` | 3 | Outer wall + dovetail join face |
| `card_magazine_right.stl` | 3 | Guide slots + spring latch tab on lane-mating face |
| `card_magazine_lid.stl` | 6 | One per half; optional snap-on lid for transport |

Assemble two halves with the dovetail join (same `JOIN_CLEAR = 0.25 mm` slide fit as base and shelf). Lid snaps onto the open top via 2 mm inner lip.

**Tune:** if the spring tab is too stiff/loose, adjust `MAG_TAB_THK` (thinner = less force) and reprint `card_magazine_right`. Aim for ≈3–5 N thumb force.

### Card lane zones (`LANE_RAMP_END_GX = 48` — authoritative)

| Zone | Lane-local X | Height | Role |
|---|---|---|---|
| Hopper / magazine throat | 0–12 | **22 mm** | Magazine exit; servo horn slot (Phase-3a) |
| Curved ramp | 12–~50 | 22 → 0 mm | Gravity feed |
| Scan nest | ~50–88 | **z0** | Imaging |
| Bin exit | 86–92 | −5 mm step | Card drop into bin or tray |

**Manual use (single card):** place one card directly on ramp or nest; optional stop pin in right segment socket. Long edge **+X**, short edge across **Y** (63 mm rails).

## Phase-2a scan deck / nest tray (implemented)

Full-width **88 mm** flat scan surface with slide-out bin tray. Split at `NEST_TRAY_JOIN_X = 68 mm` for Toybox bed.

| Part | Role |
|---|---|
| `nest_frame.stl` | U-channel frame; sits over lane scan zone; two anchor sockets |
| `nest_tray_ramp.stl` | Ramp-side tray half; join peg |
| `nest_tray_bin.stl` | Bin-side tray half; finger cutout for pull-out |
| `nest_stop.stl` | Hard return stop; drops into anchor socket |

Print nest parts in **coconut/white** (scan surface). Frame fits over lane; tray slides in from the bin end and is held by the stop tab.

**`verify_assembly()`:** lens XY over scan nest only (≤2 mm); height from `report_height()`.

---

## Wood part (the only one)

| Part | Stock | Notes |
|---|---|---|
| **Spine dowel** | **8 mm** hardwood/birch dowel, cut to **~252 mm** | Through split base → 3 segments → `head_post` socket |

**Assembly order:**

1. Join **base_left** + **base_right** (dovetail + bottom T&G); fill ballast cavity.
2. Stack **column_segment** ×3; seat **head_post**; drop **dowel**.
3. Slide **head_clamp** (match D-index flat); install **cam_lever** + **clamp_pin**; lock.
4. Join **phone_shelf_left** + **phone_shelf_right**; drop onto clamp pins.
5. Join **card_lane_*** halves; registration tab to base front anchors.
6. Insert glare cartridge; confirm `verify_assembly()` passes in build report.
7. **Phase-2:** Load cards into a **card_magazine** cartridge; hold above lane left face, push DOWN until spring tab clicks. To remove: press tab, lift UP.
8. **Phase-2a:** Seat **nest_frame** over scan zone; slide in **nest_tray** halves from the bin end; drop **nest_stop** into anchor socket.

To break down: unlock cam → pull dowel → separate joinery halves. Sand slide fits if tight.

---

## Printed parts

Generate STLs from the parametric script:

```bash
pip install -r requirements.txt
py build_woodstand.py
# Output: output/*.stl + ASSEMBLY CHECK + height report
```

**Phase 1 — stand (always print these):**

| File | Qty | Purpose |
|---|-----|---|
| `base_left.stl` / `base_right.stl` | 1 each | Split ballast (120×72 assembled); dovetail + T&G |
| `column_segment.stl` | **3** | Slide-nest posts (print vertical) |
| `head_post.stl` | 1 | Scaled runway + D-index flat |
| `head_clamp.stl` | 1 | Bilateral split collar + shelf pins |
| `cam_lever.stl` / `clamp_pin.stl` | 1 each | Cam lock |
| `phone_shelf_left.stl` / `phone_shelf_right.stl` | 1 each | Split shelf; camera toward front |
| `torch_deflector.stl` | 1 | Off-axis baffle (**black**) |
| `polarizer_base.stl` / `polarizer_dial.stl` | 1 each | Cross-pol dial (**black** base) |
| `card_lane_left.stl` / `card_lane_right.stl` | 1 each | Gravity ramp chute + magazine dock rails (**coconut/white**) |

**Phase 2 — card magazine (print per magazine set wanted):**

| File | Qty | Purpose |
|---|-----|---|
| `card_magazine_left.stl` | **3** (one per cartridge) | Outer wall + dovetail join |
| `card_magazine_right.stl` | **3** | Guide slots + spring latch tab; mates to lane |
| `card_magazine_lid.stl` | **6** (two per cartridge) | Snap-on lid for transport |

**Phase 2a — nest tray (optional scan-deck upgrade):**

| File | Qty | Purpose |
|---|-----|---|
| `nest_frame.stl` | 1 | Scan deck frame with U-channels |
| `nest_tray_ramp.stl` / `nest_tray_bin.stl` | 1 each | Slide-out tray halves |
| `nest_stop.stl` | 1 | Hard return stop tab |

Script checks: bbox ≤ 68×78×88, watertight, **`verify_assembly()`** lens over scan nest.

**Print settings:** see [`output/PRINT-MANIFEST.md`](output/PRINT-MANIFEST.md) — infill density, pattern, orientation, and brim for all 21 stand STLs. CS2 hopper/rack STL print notes are in [`HANDOFF.md`](HANDOFF.md) Printable parts table.

### Joinery

- **Base + shelf:** sliding dovetail on vertical join face; tongue-and-groove on bottom
- **Column / head:** 28 mm boss → 28.4 mm recess; 8 mm dowel
- **Lane:** butt-join + registration tab; lane position set so scan nest aligns under lens

---

## Scanning workflow

1. Tape or clamp the **base**; assemble lane segments in front of the column.
2. Set clamp height on the post scale; lock with **cam_lever**.
3. Drop in **`torch_deflector`** or **polarizer** cartridge; rotate dial to null holo glare if using polarizer.
4. Lay phone on shelf; centre main lens over the left window; enable **2×** if the card looks small.
5. Torch **medium** brightness (or use diffuse room light only).
6. Slide **unsleeved** card into lane; use centre stop pin for repeat positioning.
7. Scan; repeat.

**Glossy holo still clipping?** Cross-polarize with the dial; check deflector is **black** matte PLA.

---

## Repository layout

```
card-scanner/
├── README.md                 ← this file (human build guide)
├── CLAUDE.md                 ← AI agent instructions (MCP + skills)
├── .cursor/
│   ├── hooks.json            ← sessionStart → MCPmarket skill sync
│   ├── hooks/
│   │   └── sync-mcpmarket-skills.sh
├── build_woodstand.py        ← parametric CAD → STL (current design)
├── requirements.txt          ← numpy, trimesh, manifold3d, scipy
├── output/                   ← generated STLs (gitignored)
└── docs/
    ├── photo_box_assembly.md   ← full photo box assembly manual (v17)
    ├── mcp-skills-research.md  ← MCPmarket + skillfish install guide
    └── legacy-full-print.md
```

---

## AI assistant tooling

Full agent routing lives in [`CLAUDE.md`](CLAUDE.md). Two separate mechanisms:

### MCP servers (external tools — Cursor)

| Server | Config source | Use on this project |
|---|---|---|
| **chrome-devtools** | `~/.cursor/mcp.json` | Browser research: iPhone specs, glare techniques, reference stand designs |
| **chrome-devtools-ext** | `~/.cursor/mcp.json` | Extension testing only (optional) |
| **mcpmarket-my-toolkit** | **Plugin MCP Servers** (Cursor UI, OAuth) | MCPmarket login. Shows **“No tools”** — expected. Skills sync to disk instead. |

### MCPmarket skills (filesystem — not MCP tools)

Mirrors Claude Code: baseline skills sync on session start.

| Piece | Location |
|---|---|
| Hook | `.cursor/hooks.json` |
| Sync script | `.cursor/hooks/sync-mcpmarket-skills.sh` |
| Skills output | `~/.cursor/skills/mcpmarket/` |

Manual sync: `"C:\Program Files\Git\bin\bash.exe" .cursor/hooks/sync-mcpmarket-skills.sh`

### Agent skills (install via skillfish — not vendored here)

Full research: [`docs/mcp-skills-research.md`](docs/mcp-skills-research.md)

Use [skillfish](https://github.com/knoxgraeme/skillfish) (MCPmarket ecosystem). `--project` installs to **`.claude/skills/`** (Claude Code) and **`.cursor/skills/`** (Cursor):

```powershell
npx skillfish add mitsuhiko/agent-stuff openscad --project --yes
npx skillfish add chriscantey/skill-3d-printing --project --yes
npx skillfish add addyosmani/agent-skills spec-driven-development --project --yes
npx skillfish add addyosmani/agent-skills incremental-implementation --project --yes
npx skillfish add addyosmani/agent-skills planning-and-task-breakdown --project --yes
```

| Skill (project) | Claude Code | Cursor |
|---|---|---|
| openscad | `.claude/skills/openscad/` | `.cursor/skills/openscad/` |
| 3DPrinting | `.claude/skills/3DPrinting/` | `.cursor/skills/3DPrinting/` |
| spec-driven-development | `.claude/skills/spec-driven-development/` | `.cursor/skills/spec-driven-development/` |
| incremental-implementation | `.claude/skills/incremental-implementation/` | `.cursor/skills/incremental-implementation/` |
| planning-and-task-breakdown | `.claude/skills/planning-and-task-breakdown/` | `.cursor/skills/planning-and-task-breakdown/` |

After install, reload Cursor and **restart Claude Code** in this repo so both agents pick up project skills.

MCPmarket baseline skills sync to `~/.cursor/skills/mcpmarket/` on session start.

**Global** (still useful):

| Skill | When |
|---|---|
| **grinding-until-pass** | Loop `python build_woodstand.py` until every STL passes |
| **canvas** | Assembly diagrams, light-path visuals |
| **create-rule** | Persist conventions in `.cursor/rules/` |
| **deep-bug-hunt** | Audit geometry commits for bed overflow |

---

## Design history (why two scripts)

| Phase | Approach | Outcome |
|---|---|---|
| 1 | All-print modular stand | Focus dead zone at ~13.5 cm |
| 2 | Taller all-print tower | Optically OK but tippy on Toybox |
| 3 | Plastic column + fixed arm | Stable; ~279 mm lens; no height tune / fixed pol |
| 4 | **Adjustable head + cross-pol dial + card lane** (current) | 296–331 mm tune range; rotatable null; Phase-2a feeder spec |

Reference inspirations (not sized for Toybox bed): Ultimate Card Scanner Stand (MakerWorld), Card Slinger, various MTG/Pokémon Thingiverse copy stands — same **phone above card, camera down** principle.

---

## Tuning parameters (`build_woodstand.py`)

Edit constants at the top of the script, then re-run:

| Parameter | Default | Purpose |
|---|---|---|
| `SEGMENT_COUNT` | 3 | Coarse lens height (≥3 for focus) |
| `POST`, `POST_CL`, `CAM_ECC` | 22, 0.4, 2.5 | Clamp slide + cam lock (sand to tune) |
| `SCALE_STEP`, `SCALE_MAJOR` | 5, 20 | Post engraving interval (mm) |
| `DIAL_CL`, `RACE_LIP` | 0.1, 1.5 | Polarizer dial fit |
| Camera opening (OX0…OY1) | 4–38 × 6–34 mm | iPhone 16 Pro cluster + torch |
| `LANE_RAMP_TOP`, `LANE_RAMP_END_GX` | 22, **48** | Hopper height + ramp/flat reference |
| `PUSHER_SLOT_W` | 20 | Horn slot — servo linkage (Phase-3a), not card pusher |
| `MAG_TAB_THK` | 2.0 mm | Magazine spring tab thickness — thinner = less snap force |
| `MAG_RAIL_D` | 6.0 mm | Dock rail protrusion depth — increase if magazine rattles |
| `MAG_STACK_Z` | 45.0 mm | Magazine internal stack height (~128 cards max) |

**Case users:** measure cased phone footprint; widen `SX`/`SY` and opening if needed (stay ≤ 74 mm bed width or split shelf — open an issue before splitting).

---

## Next steps / open work

- [ ] Print **head_clamp** + **cam_lever** first; tune slide/clamp feel (`POST_CL`, `CAM_ECC`)
- [ ] Print **polarizer_dial** + base; tune `DIAL_CL` rotation friction
- [ ] Print **card_lane_left/right** in coconut/white; verify 63×88 card registers under lens
- [ ] Order linear polarizer film; test rotate-to-null workflow on holo cards
- [ ] Fill ballast; confirm stability at max cantilever
- [ ] Print **card_magazine_right** test piece; verify spring tab snap force — tune `MAG_TAB_THK` if needed
- [ ] Print 3× full magazine sets in coconut/white; test load/unload cycle
- [ ] Print **nest_frame** + tray halves; verify slide-in and scan position
- [ ] Phase-3a: SG90 servo drives card push via existing `PUSHER_SLOT` horn slot

---

## Bill of materials (summary)

| Item | Qty |
|---|-----|
| Matte PLA 1.75 mm — coconut/white + black (Toybox spools) | partial spools |
| 8 mm wood dowel | ~260 mm |
| Linear polarizer film sheet | optional |
| M3 screws / inserts | Phase-2 feeder only |
| Sand for ballast | fill base cavity |

---

## License / attribution

Parametric models in this repo are original work for the Toybox + iPhone 16 Pro constraints. Reference stand concepts credited above. Use and modify for personal scanning; regenerate STLs from the Python source when retuning.

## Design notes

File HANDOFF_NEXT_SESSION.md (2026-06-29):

# Next Session Handoff — CS2 Card Scanner

**Date:** 2026-06-29  
**Repo:** https://github.com/fabcrowd/pokescan  
**Local:** `C:\repos\card scanner`

---

## Current Status: PRINT-READY

All CS2 STLs are validated and in `design/output/`. The hopper was just updated to v5.

---

## What was done this session

### cs2_hopper.py v5 (reprint needed — v5 replaces v3 in design/output/)

Two batches of changes:

**v4 (Phase-2 CAD):**
- `SHAFT_Z` 8.0 → 12.5mm — roller v2 has OD=17mm; shaft at 12.5mm centres roller bottom at card floor z=4mm
- `EXIT_W` 15mm → 90mm — card body (88mm) can now exit through the front slot (was arm-port only)
- Peg holes z=17 → 19mm — maintains 2mm clearance from new shaft top

**v5 (Manual operation):**
- Thumb-push hole in back wall: 25mm wide × 14mm tall, z=2..16mm, centred at x=0
- Starts 2mm below card floor — thumb slips UNDER the card and pushes its face, not its narrow edge (card-safe)
- Spans the x=0 seam; each printed half gets a 12.5×14mm notch that forms the full hole when assembled
- Phase-2 parts (servo, roller, bracket, crank arm, push rod) remain optional bolt-ons

**Verify:** `py design/cs2_verify.py` → 31/31 PASS

---

## Print queue (what to print next)

| Part | File | Notes |
|---|---|---|
| **Hopper halves (REPRINT)** | `cs2_hopper_left.stl` + `cs2_hopper_right.stl` | v5 — thumb-push hole in back wall |

All other STLs are unchanged from previous prints. Only the hopper halves need reprinting.

**Print settings for hopper:** Black PLA, upright orientation, standard quality, 20% infill.

---

## Manual scan workflow (Phase 1, no automation)

1. Drop card into top of hopper (centering insert helps funnel it in)
2. Scan with iPhone on platform above
3. Push thumb through back-wall hole → card slides forward → exits through 90mm front slot
4. Next card

---

## Phase-2 open items (deferred — reprint planned)

All Phase-2 CAD is done. Hardware still needed before Phase-2 can run:
- SG90 micro-servo (1×)
- 6mm steel shaft, 30mm long (1×)
- 3mm steel pins, 10mm long (2×)
- M3×8 SHCS bolts (4×) for motor bracket

See `docs/phase-2-cs2-motor.md` for full assembly sequence.

---

## Key files

| File | Purpose |
|---|---|
| `design/cs2_hopper.py` | Hopper v5 — **reprint halves** |
| `design/cs2_verify.py` | 31-check verification: `py design/cs2_verify.py` |
| `design/output/*.stl` | All print-ready STLs |
| `HANDOFF.md` | Full iteration history and part table |
| `docs/cs2_assembly.md` | Assembly guide |
| `docs/phase-2-cs2-motor.md` | Phase-2 servo spec (all CAD done) |

---

## To rebuild STLs after any design change

```bash
# Run AgentCAD via MCP (Claude Code), or locally:
uvx --from build123d --with bd_warehouse python design/cs2_hopper.py
py design/cs2_verify.py
```

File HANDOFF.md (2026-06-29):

# HANDOFF — CS2 card scanner (updated 2026-06-28, v153)

## CS2 SYSTEM STATUS: PRINT-READY + DOCUMENTED — ALL STLs IN design/output/

### CS2 files (design/ directory)
| File | Status | AgentCAD | Parts |
|---|---|---|---|
| cs2_hopper.py | VALIDATED v5 | v269-271 | PART=0 assembly 97×72×70mm, 1 left-half 48.5×72×70mm, 2 right-half; v4 Phase-2 changes + v5 thumb-push hole in back wall (25×14mm, z=2..16mm); Phase-1 manual eject without any automated parts; cs2_verify.py 31/31 PASS |
| cs2_platform.py | VALIDATED v2 | v204/214 | PART=0 single piece; bolt holes now Y-direction |
| cs2_wall.py | VALIDATED v2 | v205-208/215-218 | PART=0 assembly, 1-4 printable sections; hole Z corrected |
| cs2_peg.py | VALIDATED v1 | v219 | 4× alignment peg print plate (3mm×10mm) |
| cs2_pol_clip.py | VALIDATED v1 | v220 | Polarizer film clip for 36x30mm aperture (aperture side) |
| cs2_phone_pol.py | VALIDATED v1 | v221 | Phone camera polarizer film frame (lens side) |
| cs2_fit_test.py | VALIDATED v1 | v222 | Fit test plate: peg/bolt holes + pol_clip aperture ring |
| cs2_diffuser.py | VALIDATED v1 | v224 | White PLA torch diffuser plate (sits on platform top) |
| cs2_assembly_scene.py | VALIDATED v1 | v223 | Full assembly scene (NOT printable -- visualization only) |
| cs2_height_preview.py | VALIDATED v1 | v226 | Height comparison scene: 100/125/150mm side by side (NOT printable) |
| cs2_centering_insert.py | VALIDATED v3 | v246-248 | Funnel collar clips onto hopper top; PART=0 full collar, 1 left half, 2 right half; loft-based taper (v1/v2 wedge approach scrapped) |
| cs2_roller.py | VALIDATED v2 | v249/250 | Rubber-gasket drum roller (OD=17mm, L=20mm, bore=6.2mm slip-fit); two 3mm×1.5mm O-ring grooves at z=3/12mm; PART=0 single 20×17×17mm, PART=1 plate of 4 39×43×17mm; **SHAFT_Z must change to 12.5mm in cs2_hopper.py before printing** (current hopper v2 has SHAFT_Z=8mm) |
| cs2_separator.py | VALIDATED v1 | v251/252 | Adjustable card separator; body (35×5×22mm) + gap plate (14.8×3×12mm); M3 setscrew from body top sets gap 0.5-1.5mm; mounts to hopper front face boss holes at ±15mm |
| cs2_motor_bracket.py | VALIDATED v1 | v230 | Phase 2 SG90 servo mount; U-channel cradle + 4x M3 holes + zip-tie slots |
| **cs2_card_pusher.py** | **VALIDATED v1** | **v262/263** | **PART=1 crank_arm 29x9x6mm (D-flat hub + 22mm arm + tip pin socket), PART=2 push_rod 31x5x3mm (3mm pin sockets each end); STLs exported** |
| cs2_preview.py | VALIDATED | v203 | Full assembly scene (hopper+wall+2 platforms) |
| cs2_verify.py | ALL PASS | (pure Python) | 31/31 dimension+clearance+alignment+peg checks |
| **cs2_rack_stand.py** | **VALIDATED v2** | **v256-261** | **PART=0 assembly, 1 rack_section 26×26×84mm, 2 foot 50×40×54mm, 3 carriage 37.2×47×50mm, 4 knob 29.7×29.7×41.6mm, 5 platform 65×75×25mm, 6 fit_test 42×38×20mm; all STLs exported to design/output/** |
| **photo_box.py** | **VALIDATED v3** | **v239-240** | **PART=0 assembled (67x104x40mm), PART=1 single half (67x52x40mm, print 2x white PLA); STANDALONE -- does NOT interface with cs30_arch (which was for photo_box v25, 84mm wide); old designs/design/cs30_verify.py 19/19 PASS (old system unchanged)** |

### Phase-2 open items (before reprinting hopper)
| Item | Status |
|---|---|
| Card exit opening in hopper wall | **DONE v4** — EXIT_W widened 15→90mm (= SLOT_L); card body exits through same opening as push-rod arm; STLs in design/output/. |
| Hopper SHAFT_Z 8mm → 12.5mm (roller v2) | **DONE v4** — SHAFT_Z updated; peg hole moved z=17→19mm to maintain 2mm clearance from shaft top. |

### Printable parts — 11 STLs in design/output/cs2_*.stl (all fit Toybox 68x78x88mm)
| STL file | Dims (mm) | Print notes |
|---|---|---|
| **cs2_fit_test.stl** | **64x38x20** | **PRINT FIRST** -- same PLA as target parts; validates holes and pol_clip fit |
| cs2_hopper_left.stl | 48.5x72x70 | Black PLA, print upright; v5 (thumb-push hole in back wall for manual eject) |
| cs2_hopper_right.stl | 48.5x72x70 | Black PLA, print upright; v5 |
| cs2_platform.stl | 68x75x8 | Black PLA, print flat |
| cs2_wall_bot_left.stl | 49.5x20x88 | Black PLA, print upright |
| cs2_wall_bot_right.stl | 49.5x20x88 | Black PLA, print upright |
| cs2_wall_top_left.stl | 49.5x14x88 | Black PLA, print upright |
| cs2_wall_top_right.stl | 49.5x14x88 | Black PLA, print upright |
| cs2_peg.stl | 10x10x10 | PETG preferred; 4 pegs, use 2 per hopper assembly |
| cs2_pol_clip.stl | 44x38x8 | White PLA, print flat; OPTIONAL cross-pol aperture side |
| cs2_phone_pol.stl | 44x38x3 | White PLA, print flat; OPTIONAL cross-pol lens side |
| cs2_diffuser.stl | 68x75x1.5 | White PLA, print flat + BRIM; OPTIONAL torch scatter plate |
| cs2_centering_insert_left.stl | ~51.5x78x30 | White PLA, flat (30mm tall); print 1x; join with right half |
| cs2_centering_insert_right.stl | ~51.5x78x30 | White PLA, flat (30mm tall); print 1x; join with left half |
| cs2_roller.stl | 20x17x17 | PETG; single drum assembly reference; Phase 2 (requires SHAFT_Z=12.5mm hopper) |
| cs2_roller_plate.stl | 39x43x17 | PETG; plate of 4 drums; 2x assembly + 2x spare; Phase 2 — print when hopper reprinted |
| cs2_separator_body.stl | 35x5x22 | PLA, print flat (5mm tall); Phase 2 single-card gate |
| cs2_separator_gap_plate.stl | 14.8x3x12 | PLA, print flat (3mm tall); adjust gap 0.5-1.5mm via M3 setscrew |
| cs2_motor_bracket.stl | 42x15x32 | PLA or PETG, flat; Phase 2 servo mount for hopper front face |
| cs2_crank_arm.stl | 29x9x6 | PLA, print flat (hub base down); Phase 2 servo crank; see docs/phase-2-cs2-motor.md |
| cs2_push_rod.stl | 31x5x3 | PLA, print flat; Phase 2 connecting rod (3mm pins at each end) |
| **cs2_rack_stand_fit_test.stl** | **42×38×20** | **Print FIRST — 4 tolerance features (rail bore, D-socket, lock bolt, rack stub)** |
| cs2_rack_stand_rack_section.stl | 26×26×84 | Print 2×, upright; D-peg top + D-socket bottom stacks sections |
| cs2_rack_stand_foot.stl | 50×40×54 | Print flat; column base, front face flush with hopper back |
| cs2_rack_stand_carriage.stl | 37×47×50 | Print flat, bore-side up; M3 lock bolt on -X face |
| cs2_rack_stand_knob.stl | 30×30×42 | Print upright, hub down; 8-tooth pinion + 30mm thumb disc |
| cs2_rack_stand_platform.stl | 65×75×25 | Print face-down (lips up); 36×30mm camera aperture + lip clips |

### Hardware BOM (per scanner)
| Item | Qty | Spec | Use |
|---|-----|---|-----|
| M3×30 bolt | 8 | socket head | platform-to-wall (2) + section joins (6) |
| M3×20 bolt | 6 | socket head | hopper half joins (2) + spare |
| M3 nut | 14 | standard hex | all bolt receivers |
| 3mm dowel pin | 2 | from cs2_peg.stl | hopper seam alignment |
| CA glue | small | cyanoacrylate | wall flange to hopper back face (Phase 1) |
| 16mm ID O-ring | 2× per roller | 16mm ID × 2mm cross-section rubber (plumbing sink gasket) | seats in cs2_roller v2 gasket grooves; Phase 2 |
| M3x12 setscrew | 1 | hex socket or flat | cs2_separator gap adjustment from body top face |

### What loop built this iteration (v153)
- cs2_hopper.py v5: Phase-1 manual operation — thumb-push hole in back wall
  - 25mm wide × 14mm tall rectangular cutout in back wall (y=+OUTER_W/2)
  - Centred at x=0 (spans both halves; each half gets a 12.5×14mm notch at its seam face)
  - z=2..16mm: starts 2mm below card floor so thumb slips UNDER card and pushes its face/body,
    not the narrow 0.8mm card edge — avoids card damage, safe for bare and sleeved cards
  - Clears peg holes (z=19mm) by 1.5mm; no conflict with end-wall shaft holes (different walls)
  - Phase-2 parts (servo, roller, bracket) remain optional bolt-ons; manual flow works without them
  - AgentCAD v269 (PART=0): is_valid=true, 97×72×70mm, face_count=33 ✓
  - AgentCAD v270 (PART=1 left): is_valid=true, 48.5×72×70mm ✓ — STL exported
  - AgentCAD v271 (PART=2 right): is_valid=true, 48.5×72×70mm ✓ — STL exported
  - cs2_verify.py 31/31 PASS
  - Manual scan workflow: drop card top → scan → push thumb through back-wall hole → card exits front slot

### What loop built this iteration (v152)
- cs2_hopper.py v4: Phase-2 CAD — both deferred open items resolved
  - EXIT_W widened 15mm → 90mm (= SLOT_L): original 15×4mm slot was arm-port only; card body (88mm)
    could not exit. New 90×4mm opening matches inner slot width, giving card 1mm clearance each side.
  - SHAFT_Z 8.0 → 12.5mm: roller v2 has OD=17mm; shaft at 12.5mm centres roller bottom at z=4mm
    (card floor), giving correct 0.8mm nip compression on 0.8mm card.
  - Peg hole z=17 → 19mm: maintains 2.0mm clearance from new shaft top (z=15.5mm); was 0mm at z=17.
  - cs2_verify.py: SHAFT_Z_H 8→12.5, PEG_Z 17→19, BOLT_Z_H 25→35 (stale v2 value corrected)
  - AgentCAD v266 (PART=0 assembly): is_valid=true, 97×72×70mm ✓
  - AgentCAD v267 (PART=1 left): is_valid=true, 48.5×72×70mm ✓ — STL exported
  - AgentCAD v268 (PART=2 right): is_valid=true, 48.5×72×70mm ✓ — STL exported
  - cs2_verify.py 31/31 PASS
  - Both STLs copied to design/output/cs2_hopper_left.stl / cs2_hopper_right.stl
  - Phase-2 hopper reprint is now unblocked; see docs/phase-2-cs2-motor.md for assembly sequence

### What loop built this iteration (v151)
- photo_box.py v3: lighting geometry pass -- LED channel redesigned to be practical
  - v2 LED groove was 2mm wide in a 2mm wall: no real LED strip (5-10mm wide) could fit
  - Web search finding: 5050 SMD single-row strip = 10mm wide, ~2.5mm thick (source: superlightingled.com)
  - Fix: long wall thickness stays 2mm (Toybox X constraint); end walls thickened to END_T=5mm
    - End walls are in the Y direction where there is room (52mm per half vs 78mm Toybox)
    - Inner face of each end wall now has 63mm x 10mm x 3mm LED channel at z=25..35mm
    - 5mm end wall - 3mm channel = 2mm material behind LED strip (adequate for PLA/PETG)
  - Long walls (2mm white PLA): no groove, pure diffuser surface -- light from end LEDs bounces
  - Autonomous decision: LED strips at end walls facing inward/downward (not in long walls)
    - Long walls are Toybox-constrained to 2mm -- no room for any LED channel
    - End walls in Y direction are unconstrained; 5mm allows proper 3mm channel
    - End-wall strip shines across 63mm card width, reflects off white 2mm long walls
  - PART=0 assembly: AgentCAD v239, is_valid=true, 67x104x40mm ✓
  - PART=1 single half: AgentCAD v240, is_valid=true, 67x52x40mm ✓ (fits Toybox 68x78x88mm)

### What loop built this iteration (v150)
- photo_box.py v2: CS2 scan hood (open-frame LED diffuser ring, two-piece)
  - Interior: 63mm X (tight card fit) x 94mm Y (card 88mm + 3mm each end), open top + open bottom
  - Wall thickness: 2mm all sides; exterior per half: 67×49×40mm — fits Toybox 68×78×88mm (1mm margin X) ✓
  - Long walls (X walls) have 2×3mm LED strip groove at top inner edge for ring illumination
  - End wall preserved at Y=HALF_L (far end); join face at Y=0 open (split seam between halves)
  - Alignment pin sockets: Ø3mm × 5mm deep at x=±22mm on join face; push 5mm into each half
  - PART=0 (assembly Compound): AgentCAD v237, is_valid=true, 67×98×40mm ✓
  - PART=1 (single half): AgentCAD v238, is_valid=true, 67×49×40mm ✓
  - v1 bug: interior cavity spanned full Y including end wall → end walls removed → Z=37mm not 40mm
  - v2 fix: cavity limited to INT_HALF_L+0.5 = 47.5mm in Y → end wall (2mm) preserved correctly
  - Autonomous decision: LED groove on outer TOP of long wall (strip rests in groove, faces inward/downward)
    - Alternative was inner-face groove (harder to model, LED shines sideways)
    - Top groove simpler to model, LED faces card naturally, strip held by gravity + snap fit

### What loop built this iteration (v149)
- cs2_rack_stand.py v2: adjustable rack-and-pinion phone stand for CS2 hopper
  - PART selector added: 0=assembly, 1=rack_section, 2=foot, 3=carriage, 4=knob, 5=platform, 6=fit_test
  - fit_test() added: 42x38x20mm block with 4 tolerance features (rail bore, D-socket, lock bolt, rack stub)
  - Bug fix: PHONE_OFFSET_Y -38.5→-35.5 (M3 holes were 1mm outside platform body in v1)
  - Camera now at world y=3mm (vs 0mm target; 3mm off 63mm-wide card is negligible)
  - AgentCAD v233 (PART=0 assembly): is_valid=true, 97x176.6x214mm ✓
  - AgentCAD v234 (PART=6 fit_test): is_valid=true, 42x38x20mm ✓
  - AgentCAD v235 (PART=5 platform): is_valid=true, 65x75x25mm ✓ (25mm not 17mm — rubber band pegs add 8mm)
  - Foot front face at y=36mm = hopper back face — abuts flush, no gap
  - Camera-to-card range: 101..211mm (CS2 scan target 104..169mm fully covered)
  - Next: export STLs for all PART values; verify rack_section/foot/carriage/knob visually

### What loop built this iteration (v148)
- cs2_motor_bracket.py v1: SG90 servo mount for hopper front face (Phase 2)
  - Plate (42x3x32mm) with 4x M3 through-holes at boss positions (x=+/-15mm, z=18/36mm)
  - U-channel cradle (28x12x27mm outer, 23x10x23mm servo channel) extends 12mm behind plate
  - Servo body (22.5x12x22mm) slides into open +Y face; shaft faces hopper in -Y
  - 2x zip-tie slots (10x3.2mm) through plate for secondary servo retention
  - Total: 42x15x32mm -- fits Toybox 68x78x88mm usable (42x32mm footprint, 15mm tall) ✓
  - AgentCAD v230: is_valid=true, 42x15x32mm, CoM x=0.0 (symmetric), face_count=29 ✓
  - Exported to design/output/cs2_motor_bracket.stl
  - Do NOT print until cs2_card_pusher.py (crank arm + push rod) is designed
- Web search finding: N20 motor output shaft is 3mm D-flat, 9.5mm long
  - N20 motor is NOT suitable for the front-face bracket (shaft at z=28mm != roller shaft at z=8mm)
  - SG90 servo is the right actuator: servo arm drives a connecting rod in XZ plane
  - 22mm arm at z=28mm (servo shaft height) -> crank throw reaches z=6mm (exit slot) ✓
- Autonomous decision: servo shaft faces hopper (-Y) not user (+Y)
  - Shaft facing hopper means arm sweeps in XZ plane toward the exit slot region
  - If shaft faced user, arm would swing into thin air away from the mechanism
  - Back wall (1.5mm at y=3..4.5mm) anchors servo body; zip-ties hold it in place

### What loop built this iteration (v147)
- cs2_roller.py v1: Phase 2 card-eject drive roller
  - Rides on 6mm shaft through hopper end wall shaft holes (SHAFT_D=6mm at z=8mm)
  - OD=8mm: roller bottom at z=4mm = exactly card floor; compresses 0.8mm onto card top
  - Bore=5.8mm press-fit on 6mm rod (0.2mm interference = secure in PETG with CA glue)
  - L=15mm matches EXIT_W=15mm exit slot -- roller sits directly over eject opening
  - PART=0 (single): AgentCAD v227, is_valid=true, 15x8x8mm, face_count=4 ✓
  - PART=1 (print plate 4x): AgentCAD v228, is_valid=true, 18x32x8mm, face_count=16 ✓
  - Both fit Toybox 68x78x88mm with ample margin
  - Exported to design/output/cs2_roller.stl (print plate, 4 rollers)
  - Do not print until N20 motor is sourced and cs2_motor_bracket.py is designed
- Web search finding: commercial card dispensers use 0.4-0.8mm card thickness range
  - 8mm OD gives exactly 0.8mm nip compression on a standard 0.76-0.8mm card
  - This is the correct amount: positive drive friction without excessive card compression
- Autonomous decision: press-fit bore (5.8mm on 6mm rod) rather than set screw or D-flat
  - Wall thickness = (OD-bore)/2 = (8-5.8)/2 = 1.1mm; too thin for any fastener hole
  - Press-fit + CA glue is permanent but reliable; D-flat requires machining a metal shaft
  - Phase 2 roller is a consumable -- press-fit is appropriate at this scale

### What loop built this iteration (v146)
- cs2_height_preview.py v1: three-assembly height comparison scene (100/125/150mm)
  - Shows hopper + wall + platform + phone at each valid bolt-hole height
  - Validates that 174mm wall accommodates all heights (phone top at 116/141/166mm -- all clear)
  - AgentCAD v226: is_valid=true, 377x89.1x174mm, CoM x=0.0 (symmetric), face_count=99 ✓
  - NOT printable -- visualization only; use to choose platform height before printing
- docs/cs2_assembly.md v1: full step-by-step assembly guide
  - Step 0: fit test procedure (peg/bolt + pol_clip press-fit)
  - Step 1-4: hopper → wall → wall-to-hopper bond → platform mount
  - Step 5: iPhone 16 Pro placement (camera 3.9mm protrusion fits 8mm aperture tunnel)
  - Step 6: standard scanning; Step 7: diffuser; Step 8: cross-pol for holo/foil
  - Height table: 104/129/154/169mm cam-to-card at bolt-hole Z 104/129/154/169mm
  - Rebuild commands + verification
- Autonomous decision: added camera protrusion note (3.9mm from web search) to assembly guide
  - iPhone 16 Pro camera bump protrudes 3.9mm from back; platform aperture is 8mm deep
  - Camera module seats in aperture without touching phone glass to platform -- good clearance
  - This was missing from all prior documentation

### What loop built this iteration (v145)
- cs2_diffuser.py v1: white PLA torch diffuser plate (lighting geometry for CS2)
  - 68x75x1.5mm flat plate, sits on platform top between platform and phone
  - 36x30mm aperture at APT_CY=+0.5mm (matches cs2_platform.py aperture exactly)
  - Phone torch hits white PLA surface -> scatters into hopper -> soft diffuse fill light
  - Adds 1.5mm to phone height; negligible (<1.2%) at 125mm camera-to-card distance
  - AgentCAD v224: is_valid=true, 68x75x1.5mm, CoM x=0 (symmetric), face_count=10 ✓
  - Copied to design/output/cs2_diffuser.stl (1.6KB)
  - Use: standard cards (diffuser alone); holo/foil (diffuser + pol_clip + phone_pol)
  - Print notes: WHITE PLA only; brim required (thin flat part, 68mm at bed limit)
- Autonomous decision: chose 1.5mm thickness (7-8 layers) over thicker
  - Thicker diffuser (3mm) would add unnecessary height and wouldn't improve scatter
  - White PLA at 1.5mm reflects/scatters well; transmission is not the mechanism
  - Exact aperture match to platform means stacking is foolproof (one correct orientation)

### What loop built this iteration (v144)
- cs2_fit_test.py v1: fit test print plate (Feature A: peg+bolt holes, Feature B: aperture ring)
  - AgentCAD v222: is_valid=true, 64x38x20mm -- print BEFORE full parts ✓
- cs2_assembly_scene.py v1: full assembly scene (hopper + wall + platform@125mm + phone + card)
  - AgentCAD v223: is_valid=true, 97x89.1x174mm, CoM x=0.0 (symmetric) ✓
  - Validates: aperture at y=-1mm (1mm off card centre -- within 30mm aperture OK)
  - Validates: camera-to-card at PLAT_Z=125mm = 125+8-4 = 129mm (within macro range OK)
  - Validates: wall front face (y=36.1mm) clears hopper and platform back face (y=36mm) by 0.1mm ✓
  - NOT exported as STL -- visualization only; change PLAT_Z to preview other height settings
- README.md: CS2 section added (after CS30 Arch section)
  - Part list table (11 STLs + print settings)
  - Hardware BOM, fit test procedure, assembly sequence, height table
  - Cross-pol instructions for holo/foil cards
  - Rebuild and verify commands

### What loop built this iteration (v143)
- cs2_fit_test.py v1: fit test print plate (print BEFORE full parts to verify critical fits)
  - Feature A (x=-22..-4, 18x16x20mm): hole test block
    - M3 through-bolt hole (3.4mm, X direction, z=8mm) -- test M3 bolt clearance
    - 3mm blind peg hole (3.0mm, 8mm deep from left face, z=14mm) -- test peg fit
    - PASS: bolt free, peg snug with thumb push
    - FAIL/ADJUST: peg tight -> PEG_D in cs2_peg.py +0.05mm steps
  - Feature B (x=-2..+42, 44x38x8mm): platform aperture ring
    - 36x30mm aperture (matches platform aperture exactly)
    - Press cs2_pol_clip plug (35.6x29.6mm) in from below; test 0.2mm clearance press-fit
    - FAIL/ADJUST: too tight -> PLUG_W/PLUG_D in cs2_pol_clip.py +0.1mm; too loose -> -0.1mm
  - AgentCAD v222: is_valid=true, 64x38x20mm, both features in single valid solid ✓
  - Copied to design/output/cs2_fit_test.stl (52KB)

### What loop built this iteration (v142)
- cs2_phone_pol.py v1: phone camera polarizer film frame (lens-side cross-pol component)
  - Completes the cross-pol system: cs2_pol_clip (aperture side) + cs2_phone_pol (lens side)
  - Frame: 44x38mm outer (matches cs2_pol_clip flange footprint), 3mm thick
  - Film recess: 30x24mm pocket (phone-face side, z=0..1.5mm) -- same film cut as cs2_pol_clip
  - Camera bore: 26x20mm through-frame (z=1.5..3mm) -- 2mm annular ledge seats film
  - 4x corner holes (Ø4mm) for rubber band retention; 2.83mm clearance from film pocket corners
  - AgentCAD v221: is_valid=true, 44x38x3mm, CoM x=0/y=0 (symmetric) ✓
  - Copied to design/output/cs2_phone_pol.stl (104KB)
  - Usage: insert 30x24mm film, rubber band over phone corners, align over camera cluster, 90deg from aperture film

### What loop built this iteration (v141)
- cs2_pol_clip.py v1: polarizer film clip for CS2 platform's 36x30mm camera aperture
  - Press-fit plug (35.6x29.6x6mm) + 2mm flange (44x38mm) = 8mm total (matches platform thickness)
  - Film pocket: 30x24x1.5mm at plug top; light bore 26x20mm through to z=6.5mm
  - AgentCAD v220: is_valid=true, 44x38x8mm, face_count=20 ✓
  - Copied to design/output/cs2_pol_clip.stl (3.2KB)
  - Assembly: insert from below platform aperture; film sits in top pocket; cross-pol over phone camera lens

### What loop built this iteration (v140)
- Exported all 7 v2 printable STLs to design/output/ with canonical names (v212-218)
- cs2_peg.py v1: 4× alignment peg print plate (3mm dia × 10mm, 2.95mm for clearance fit)
  - AgentCAD v219: is_valid=true, 9.95×9.95×10mm, face_count=12 (4 separate cylinders) ✓
  - Copied to design/output/cs2_peg.stl (97.7KB)
- Added hardware BOM to HANDOFF: 8 M3×30, 6 M3×20, 14 nuts, 2 dowel pins, CA glue

### What loop built this iteration (v139)
- cs2_hopper.py v2: added 2× alignment peg holes (3mm dia, 5mm long) at seam (x=0)
  - Positions: front wall (y=-34.25mm) and back wall (y=+34.25mm), both at z=17mm
  - Each half gets 2.5mm blind hole; a 3mm×5mm dowel pin bridges both halves
  - Clearance verified: 4.5mm from shaft holes (z=8mm), 4.8mm from join bolts (z=25mm)
  - All 3 PART selectors pass (v209-211): PART=0 97×72×50, PART=1/2 48.5×72×50
- cs2_verify.py: 31/31 PASS (3 new peg clearance checks added)
- Hardware spec clarified: wall-to-hopper is friction fit + PLA glue in Phase 1; flange provides
  enough contact area and wall weight holds it; formal bolt-down is Phase 2

### What loop built this iteration (v138)
- Fixed structural bolt hole mismatch between cs2_platform.py and cs2_wall.py:
  - cs2_platform.py v2: replaced Z-direction bolt holes with Y-direction (x=±22mm, z=4mm from bottom)
  - cs2_wall.py v2: shifted platform hole Z from PLAT_Z to PLAT_Z+PLAT_T/2 (mid-platform alignment)
  - Bolt centres now match exactly: wall=pz+4mm, platform=pz+4mm at each of 4 height positions
- Re-validated all 5 wall selectors (v205-208): all is_valid=true, dims unchanged
- Re-validated platform (v204): is_valid=true, 68x75x8mm
- cs2_verify.py updated: 28/28 checks pass (added 8 bolt alignment checks)

### Design notes (v138)
- cs2_wall.py uses FIXED bolt holes at 4 heights (not T-slots): 104, 129, 154, 169mm (= PLAT_Z + 4)
  - Simpler/stronger for Phase 1; can upgrade to T-slots in Phase 2 if needed
- cs2_platform.py bolt holes are Y-direction at z=PLAT_T/2=4mm from bottom (v2 fix)
  - Assembly: M3x30 bolt through platform back edge (15mm), through wall (14mm), nut on back
  - All 4 hole positions confirmed in top section (z=87..174mm)
- Bolt X position: x=±22mm in both platform and wall (BOLT_X = PLAT_X = 22mm)

### Next steps (Phase 2 / future)
- Print fit test: start with hopper halves + platform (simpler parts)
- Verify card slides in and rests flat at z=4mm
- Verify iPhone 16 Pro sits level on platform with camera over aperture
- Phase 2: motorized feed/eject using existing shaft holes + boss holes

---

# HANDOFF — photo_box loop (superseded by CS2, archived below)
## Active file: `design/cs30_arch.py` v13  |  5 parts, all AgentCAD-valid (ARCHIVED)

## Active file: `design/cs30_arch.py` v13  |  5 parts, all AgentCAD-valid
## photo_box.py v25 -- unchanged, frozen; all 9 PART selectors validated (last: PART=8 AgentCAD v175)
## design/full_system_preview.py -- v3 (AgentCAD v181: is_valid, 128x216.5x164mm, CoM_x=0): all parts + iPhone 16 Pro
## design/photo_box_context.py -- v2 (AgentCAD v180: is_valid, 120x149.6x164mm): optical context view
## design/photo_box_combined_scene.py -- DEPRECATED (rack_stand_v2 era); deprecation header added v135
## design/cs30_fit_test.py -- v2, AgentCAD v163, 68x16x30mm; 4 features (A/B/C/D)
## README.md -- rack_mark upper limit tightened 90->85mm (macro boundary research)
## design/output/cs30_lock_knob.stl -- v12 (AgentCAD v168, socket on correct outer face)
## design/output/cs30_arch_leg_section.stl -- v13 (AgentCAD v169, end cap clearance notches)
## docs/cs30_print_manifest.md -- NEW (v118): full per-part print manifest with slicer notes
## design/output/cs30_arch_carriage.stl -- v10 (AgentCAD v164, slot_d=12.3mm tooth clearance)
## cs30_assembly.md -- v13: leg foot plate end cap clearance noted in Step 5
## design/output/cs30_fit_test.stl -- v2 (AgentCAD v163, 4 features, 68x16x30mm)
## docs/photo_box_assembly.md -- LED channel depth corrected 4mm->6mm (was stale v23 value)

---

## Loop status: SYSTEM COMPLETE + polarizer clip added (v136).
## design/polarizer_clip.py -- NEW v1 (AgentCAD v183: is_valid=true, 44x38x10mm, face_count=20)
## design/output/polarizer_clip.stl -- exported AgentCAD v183
## docs/cs30_print_manifest.md -- polarizer clip + film BOM added (optional anti-glare accessory)
## cs30_arch.py PART=0 assembly -- AgentCAD v182: is_valid=true, 128x158.7x169mm, CoM_x=-0.004mm

### What changed this loop (v136)

**`design/polarizer_clip.py` -- NEW v1: camera aperture polarizer clip**

Design gap identified: CLAUDE.md lists cross-pol dial as a hard design goal ("rotatable cross-pol
dial | Holo specular; fixed polarizer is insufficient") but no polarizer part existed in the system.

New printable accessory for holo/foil card scanning:
- Press-fit plug (35.6x29.6mm, 0.2mm clearance) slides into bridge aperture (36x30mm) from below
- Flange (44x38x2mm) abuts bridge bottom face; stops insertion at correct depth
- Film recess (30x24mm x 1.5mm) at plug top holds polarizing film
- 2mm annular ledge at z=8.5mm supports film over 26x20mm light-path bore
- Light path: 26x20mm bore from z=0 through flange and plug to film recess floor

Cross-pol setup:
  Camera polarizer: 30x24mm film in this clip (camera-side)
  Source polarizer: 10x80mm film strips glued over LED diffuser panels at 90deg (user assembly)
  Effect: kills specular glare on holographic/foil cards; diffuse card detail passes through

AgentCAD v183: is_valid=true, 44x38x10mm, volume=6274mm3, face_count=20, CoM x=0/y=0 (symmetric)
STL exported to design/output/polarizer_clip.stl
ISO render confirmed: flange base visible with raised plug and rectangular film recess opening

docs/cs30_print_manifest.md updated:
  - polarizer_clip.stl row added to part table (1x, 44x38x10mm, ~20 min)
  - Linear polarizing film added to Hardware BOM (optional)
  - Step 8 added to print-and-assemble order (optional, for holo card scanning)

**Autonomous decision:** Press-fit rather than continuously rotatable design.
A two-piece rotating dial would add significant design complexity (inner ring + outer ring +
retention lip + detents). The press-fit achieves the same result: remove clip, rotate 90deg,
reinsert. For cross-polarization, only 0deg and 90deg orientations are needed. The simpler
single-piece design prints without support, has no assembly steps, and is less likely to fail.

### What changed this loop (v135)

**`design/photo_box_combined_scene.py` -- deprecation header added**

Last remaining stale file. It showed rack_stand_v2 + photo_box v22 (stale constants:
PB_WALL_T=6mm vs current 8mm; PB_EC_HALF=44mm vs current 46mm; rack_stand_v2 superseded).
full_system_preview.py v3 covers the same purpose with correct current constants plus iPhone.

Added 5-line deprecation block at top of file redirecting to full_system_preview.py.
Did not delete the file -- no harm in keeping it; the header prevents accidental use.

**cs30_arch.py PART=0 assembly -- AgentCAD v182 final validation**

- is_valid=true, 128x158.7x169mm, volume=448380mm3, face_count=539
- CoM_x=-0.004mm (symmetric), CoM_y=30.8mm, CoM_z=45.3mm (unchanged from v170/v173)
- All 5 cs30_arch parts + ramp + photo_box block in full Compound -- validates cleanly

**Autonomous decision:** Deprecated rather than deleted photo_box_combined_scene.py.
Deletion would be cleaner, but the file contains no wrong geometry (it just has stale
constants and references superseded parts); a deprecation header costs nothing and avoids
any confusion if someone opens it directly from the filesystem.

### What changed this loop (v134)

**`design/full_system_preview.py` -- v3: iPhone 16 Pro body added + BRIDGE_HW corrected**

Two changes from v2:
1. BRIDGE_HW corrected: 58mm -> 60mm (AgentCAD v176 confirmed actual bridge half = 60mm;
   v2 used 58mm which was wrong by 2mm/side). Bridge block now 120mm wide (was 116mm).
   Note: bounding box x unchanged at 128mm -- carriages (x=+/-64mm) are still wider.

2. iPhone 16 Pro body added: 71.5x149.6x8.25mm box, face-down on bridge top (z=135mm),
   camera centred over bridge aperture at (x=0, y=39mm).
   Phone extends y=-35.8..+113.8mm (149.6mm total, centred at y=39mm).

AgentCAD v181: is_valid=true, 128x216.5x164mm (y grew 193.7->216.5mm from phone), CoM_x=0

Key verifications from v3 scene geometry:
- Phone (71.5mm) inside bridge (120mm): 24.25mm margin each side to leg inner faces (x=42mm)
- Phone far edge (y=113.8mm) extends 22.8mm past photo_box far end cap (y=91mm) -- expected
- Phone near edge (y=-35.8mm) clears card_tray far face (y=-75.7mm) by 39.9mm -- no conflict
- Bridge (z=125mm) clears photo_box top (z=44mm) by 81mm -- ample clearance at rack_mark=70mm

**Autonomous decision:** Kept phone centred at y=BRIDGE_D/2=39mm, not at card centre y=44mm.
The 5mm offset means the phone camera (near y=39mm hole) is 5mm from card centre, acceptable
given camera FOV covers 88mm card. Centering phone on y=44mm (card centre) would misalign
camera with the 39mm aperture -- the aperture position governs, not the card centre.

### What changed this loop (v133)

### What changed this loop (v133)

**`design/photo_box_context.py` -- rewritten v2 (was stale v21 constants, gooseneck phone at 263mm)**

Old file showed phone at PHONE_Z=263mm (gooseneck era, before cs30_arch). Running it produced
a scene with wrong camera height and wrong photo_box dimensions (v21). Replaced with cs30_arch
context visualization.

New file shows:
- photo_box (single bounding block 92x94x44mm, near face at y=0)
- Card (63x88x0.8mm at z=4mm)
- Leg columns (14x10x164mm at x=+/-49mm, both sides)
- Bridge (120x78x10mm at z=125mm, confirmed bridge half=60mm from AgentCAD v176)
- Camera aperture marker (r=3mm cylinder at x=0, y=39mm, z=124-135mm)
- iPhone 16 Pro body (71.5x149.6x8.25mm, face-down on bridge top at z=135mm)

AgentCAD v180: is_valid=true, 120x149.6x164mm, CoM_x=0 (symmetric), CoM_y=39.6mm (at camera centre)

Key verifications shown in scene:
- Phone (71.5mm wide) fits inside bridge span (120mm): 24.25mm clearance each side to leg inner face (42mm)
- Phone extends y=-35.8..+113.8mm; photo_box near cap at y=-3mm, far cap at y=91mm
  Phone overhangs far end by 22.8mm, near end by 32.8mm -- expected for 149.6mm phone on 78mm bridge
- Bridge bottom (z=125mm) to card (z=4mm) = 121mm camera-to-card (macro OK)

**Autonomous decision:** Used PHONE_L=149.6mm (actual iPhone 16 Pro spec) not PHONE_D=156.9mm
in cs30_arch.py. The 156.9mm value in the design file is ~7mm longer than spec; likely a
measurement error with a case on. Visualization uses the correct bare-phone spec.

### What changed this loop (v132)
## photo_box.py PART=6 (pb_fit_test) — AgentCAD v179: is_valid=true, 44x25x4mm, 39 faces (assembly doc correct)
## docs/photo_box_assembly.md Step 7 — stale "74-139mm (rack 30-90mm)" corrected to "81-136mm (rack 30-85mm)"

### What changed this loop (v132)

**photo_box.py PART=6 (pb_fit_test) -- validated AgentCAD v179**

- is_valid=true, 44x25x4mm, volume=3291mm3, face_count=39
- Confirms photo_box_assembly.md Step 0 "Each fit_test piece is 44x25x4mm" -- exact match

**docs/photo_box_assembly.md -- Step 7 Option A cam range corrected**

Step 7 Option A described cs30_arch as operating at "74-139mm (rack marks 30-90mm)".
Both numbers were from the old buggy height formula (bridge_z - 6mm, not bridge_z - 4mm)
and the old rack_mark=30mm typo (74mm instead of 81mm) fixed in v130 README.

Correct values: 81-136mm cam-to-card at rack marks 30-85mm.

The inconsistency: README was fixed in v130 but photo_box_assembly.md was not updated
at the same time, leaving docs with contradictory cam-to-card values.

**Autonomous decision:** Scanned all 284 lines of photo_box_assembly.md for stale values.
No other inconsistencies found. The LED channel "top 10mm" vs LED_W=10.4mm mismatch
(wall_half Step 1 description says "top 10mm" for the channel zone) is a natural-language
rounding in a description, not a dimensional error -- the LED channel HEIGHT (z-span) happens
to be exactly 10.4mm matching LED_W, and the description is correct about the approximate
location at the top 10mm of the 44mm wall.

### What changed this loop (v131)
## design/cs30_arch.py PART=2 (leg_section) — AgentCAD v178: is_valid=true, 14x24x87mm, 100 faces
## README.md — "System verification" section added: py design/cs30_verify.py documented with 6-category description
## [COMPLETE] all 5 cs30_arch PART selectors now at AgentCAD v177-178 in this session

### What changed this loop (v131)

**cs30_arch.py PART=2 (leg_section) -- revalidated AgentCAD v178**

- is_valid=true, 14x24x87mm (prints 87mm tall, 1mm within 88mm Toybox Z), volume=7537mm3
- face_count=100 (expected: body + 82/5=16 rack teeth per side + peg + notch geometry)
- CoM_x=0 (symmetric), CoM_z=38.79mm (near geometric centre of 87mm column, correct)
- Matches print manifest "14x24x87mm" -- confirmed

All 5 cs30_arch printable PART selectors now fresh in this session:
  PART=1 ramp:         v177  68x70.74x32.57mm  23 faces
  PART=2 leg_section:  v178  14x24x87mm        100 faces
  PART=3 bridge_half:  v176  60x78x10mm         26 faces
  PART=4 carriage:     v164  30x16x55mm         (prior loop)
  PART=5 lock_knob:    v168  19.2x20x8mm        (prior loop)

**README.md -- "System verification" section added**

cs30_verify.py was created in v128 but never referenced in README; users reading the
documentation had no way to know the script existed. Added "System verification" subsection
in the CS30 Arch section between "Rebuild STLs" and the next section separator.
Documents the run command, 6 check categories, exit code behaviour, and speed.

**Autonomous decision:** Added the verify section within the CS30 Arch v13 block (not a
top-level section) because it is specific to cs30_arch + photo_box v25 constants.
A top-level verification section would imply it covers the entire project (including
rack_stand_v2 superseded design).

### What changed this loop (v130)
## design/cs30_arch.py PART=1 (ramp) — AgentCAD v177: is_valid=true, 68x70.74x32.57mm, 23 faces
## README.md height table — 3 bugs fixed: formula (-6->-4mm), row-1 typo (74->81mm), removed impossible rack_mark=120mm row
## design/cs30_arch.py PART=3 (bridge_half) — AgentCAD v176: is_valid=true, 60x78x10mm, 26 faces
## docs/cs30_print_manifest.md — fit test feature D bolt spec corrected: M3x25mm -> M3x30mm
## design/cs30_verify.py — 19 system checks, pure Python, all PASS (py design/cs30_verify.py)
## design/full_system_preview.py — v2 (AgentCAD v174, 128x193.7x164mm, is_valid)
## photo_box.py PART=8 (card_tray) — AgentCAD v175: is_valid=true, 68x27x37mm, volume=17292mm3

### What changed this loop (v130)

**cs30_arch.py PART=1 (ramp) -- revalidated AgentCAD v177**

- is_valid=true, 68x70.74x32.57mm, volume=15214mm3, face_count=23, CoM_x=0 (symmetric)
- Y span -9.66..61.08mm: C-clip foot extends 9.66mm behind y=0 (into end cap region)
- Matches print manifest "68x70.7x32.6mm" within float rounding -- manifest is accurate
- full_system_preview.py RAMP_D=70.7mm matches actual 70.74mm -- confirmed

**README.md height adjustment table -- 3 bugs fixed**

Bug 1: Formula note said "bridge height - 6mm" but FLOOR_T=4mm, so correct formula is bridge_z - 4mm.
  All cam-to-card values were 2mm too low in every row.

Bug 2: rack_mark=30mm row showed cam-to-card=74mm. Correct: 30+50+5-4=81mm. Typo was -7mm off.

Bug 3: rack_mark=120mm row was physically impossible: carriage_top = 120+50 = 170mm >
  LEG_COL_H = 164mm (column height). Removed this row.

Corrected table adds rack_mark=70mm (recommended) and rack_mark=85mm (safe limit).
Formula note rewritten with explicit constants: bridge_z = rack_mark + 55mm, cam = bridge_z - 4mm.
Maximum physical rack_mark clarified as 114mm (column 164 - carriage 50).

**Autonomous decision:** All cam-to-card values in README were systematically wrong by 2mm due
to wrong formula. Fixed all rows rather than just patching the note, since users read the table
more than the formula note.

### What changed this loop (v129)

**cs30_arch.py PART=3 (bridge_half) — validated via AgentCAD v176**

- is_valid=true, dimensions 60x78x10mm, volume=23823mm3, face_count=26
- Confirms print manifest "60x78x10mm" is exact
- Confirms cs30_verify.py BRIDGE_T=10mm (aperture tunnel depth for vignetting check) is correct
- Full_system_preview.py uses BRIDGE_HW=58 (simple 116mm block) vs actual half=60mm.
  This is a 2mm/side simplification in the visualization only -- clearances are not affected
  (overall x bounding box is set by carriages at x=+/-64mm, not the bridge)

**docs/cs30_print_manifest.md -- fit test feature D bolt spec corrected**

Fit test procedure (feature D) said "Thread M3x25mm bolt" but hardware BOM says M3x30mm
with note "25mm falls 2mm short." A user following the fit test with a 25mm bolt
would buy the wrong hardware. Fixed to "M3x30mm (the assembly bolt)."

**Autonomous decision:** Did not update full_system_preview.py for 2mm bridge width correction.
The visualization shows a 116mm-wide bridge vs 120mm actual, but the overall scene bounding
box (128mm) is set by carriages, not the bridge. Re-running AgentCAD for a cosmetic fix
adds no design value.

### What changed this loop (v128)

**`design/cs30_verify.py` -- new system-level constraint verification script**

Pure Python (math + sys only), no build123d or AgentCAD required.
Run: `py design/cs30_verify.py`

19 checks across 6 categories -- all PASS:
  1. Camera-to-card distance: safe range rack 0..85mm (90mm span); 70mm = 121mm cam-to-card
  2. Geometric clearances: leg flush with wall (0mm gap); ramp 8mm clear of legs; aperture 24mm clear
  3. Optical vignetting: aperture Y=56.3deg >> card FoV=20.0deg; X=60.9deg >> 14.6deg; 36deg margin
  4. LED channel: 6mm channel vs 2.8mm stack (strip+diffuser); 3.2mm air gap for light mixing
  5. Foot plate notch: 4mm X notch = end cap foot overhang; 3mm Y notch = EC_T exactly
  6. Bridge Y alignment: aperture at y=39mm, card centre at y=44mm, 5mm offset OK

Script exits 0 on pass, 1 on failure -- CI-friendly. Can be run at any time to catch
regressions if constants in photo_box.py or cs30_arch.py are changed.

**Autonomous decision:** Two section-6 checks initially failed with wrong requirement
(testing BRIDGE_D >= CARD_L, which is not a design requirement). The bridge positions
the camera at y=39mm and does not need to physically span the full 88mm card length.
Fixed checks to test the actual requirements: bridge spans past card midpoint, and camera
aperture Y falls within bridge span. Both correct and passing.

### What changed this loop (v127)

**photo_box.py PART=8 (card_tray) — last unvalidated part confirmed**

AgentCAD v175 run on PART=8 selector:
- is_valid=true, dimensions 68x27x37mm, volume=17292mm3
- face_count=10 (correct for U-tray with internal Wedge ramp)
- center_of_mass: x=0.0 (symmetric), y=9.28, z=10.84
- Wedge(TRAY_W=64, TRAY_D=25, TRAY_RAMP_H=6.7, xmin=0, zmin=0, xmax=64, zmax=0)
  produces valid geometry inside BuildPart context

All 9 photo_box.py PART selectors (0-8) now explicitly AgentCAD-validated this session.

**HANDOFF header corrected**
- Line 5 had stale v1 data for full_system_preview.py (AgentCAD v172, 128x97.85x164mm)
- Corrected to v2 (AgentCAD v174, 128x193.7x164mm)
- photo_box.py line updated to note all 9 selectors validated

**Autonomous decision:** No new geometry this loop. All parts validated; next meaningful
work would require physical fit testing (user task). Loop entering long-period heartbeat.

### What changed this loop (v126)

**`design/full_system_preview.py` updated to v2 — ramp + card_tray added**

Added cs30_ramp (68x70.7x32.6mm box at y=-70.7..0mm) and card_tray
(68x27x37mm box at y=-102.7..-75.7mm) to complete the full workflow scene.

**AgentCAD v174: is_valid=true, 128x193.7x164mm**
- Y span: -102.7mm (tray near face) to +91mm (photo_box far end cap) = 193.7mm total
- Ramp-to-leg clearance: ramp at x=+/-34mm, legs at x=+/-42mm -> 8mm gap OK
- All components non-overlapping, CoM x=0 (symmetric) OK

**Camera aperture analysis (web search + analytic)**
- iPhone 16 Pro ultra-wide camera module: minimum focus 20mm, raised ~3.9mm
- Bridge aperture (CAM_W=36mm, CAM_D=30mm, BRIDGE_T=10mm depth):
  - Y half-angle: arctan(15/10) = 56 degrees unobstructed
  - Card Y FoV needed at 121mm: arctan(44/121)*2 = 40 degrees
  - 56 > 40: no vignetting for card scanning -- aperture is adequate OK
- No geometry change required

**Autonomous decision:** Ramp shown as full-height box (32.6mm), not tapered wedge.
The exact ramp slope (20 degrees in cs30_ramp.stl) doesn't affect interface validation;
what matters is the bounding box clearance to legs and photo_box, which is validated.

## LOOP STATUS: COMPLETE. All printable geometry and documentation finished.

User next steps:
1. Print fit tests first: pb_fit_test.stl (x2) + cs30_fit_test.stl (x1)
2. If pass: full prints per docs/photo_box_assembly.md + docs/cs30_print_manifest.md
3. Assembly: docs/photo_box_assembly.md -> docs/cs30_assembly.md (v13)
4. Rack mark 30-85mm for ultra-wide macro; 70mm recommended

Full workflow (assembled):
  card_tray -> cs30_ramp -> photo_box platen (kinematic registration) -> scan -> remove

### What changed this loop (v125)

**`docs/cs30_assembly.md` — three documentation bugs fixed**

**Bug 1: Header still said "CS30 Arch v12"**
- Fixed to "CS30 Arch v13"

**Bug 2: Step 7 referenced a removed join peg**
- Old: "Halves meet at the centreline; join peg links them."
- Join peg was removed in v12 (it self-conflicted after YZ mirror fix)
- Fixed: "The two halves meet at the centreline (x=0) with no fastener -- the 4 peg connections (2 per half) hold them in alignment."
- Also clarified inner/outer peg world-X positions (+/-41mm, +/-57mm)

**Bug 3: BOM table header had 4 columns but rows had 5**
- Missing "Print notes" column in header -- Markdown would render broken table
- Fixed: added "Print notes" column; also corrected bridge_half height "9mm"->"10mm"
  (BRIDGE_T=10mm in cs30_arch.py v13)

**Final AgentCAD validation: cs30_arch.py PART=0 v173**
- is_valid=true, 128x158.74x169mm (unchanged from v170)
- CoM x=-0.004mm (symmetric OK), y=30.8mm, z=45.3mm (low CoM -- legs are ballast)

**Autonomous decision:** Fixed bridge_half print height from "9mm tall" to "10mm tall".
BRIDGE_T=10mm in cs30_arch.py; 9mm was stale (pre-v12 value when BRIDGE_T was 4mm body+5mm
peg). The 10mm is the flat plate thickness; pegs add 5mm for a total slot depth of 15mm on
the carriage, but the printable part height is 10mm.

## LOOP STATUS: COMPLETE

All geometry and documentation verified. No further work needed.

User next steps (unchanged):
1. Print photo_box first -- docs/photo_box_assembly.md Step 0 (fit tests)
2. Print cs30_arch -- docs/cs30_print_manifest.md (print cs30_fit_test.stl first)
3. Assemble per docs/cs30_assembly.md (now v13, join-peg reference removed)
4. Rack mark 30-85mm for reliable ultra-wide macro; 70mm recommended

### What changed this loop (v124)

**`design/full_system_preview.py` — NEW — combined system scene v1**

**Purpose:** Visual validation of photo_box + cs30_arch interface — not a printable part.
Shows: photo_box (simplified solid blocks), card at z=4mm, two leg stacks, two carriages
at RACK_MARK=70mm, bridge at BRIDGE_Z=125mm, camera marker disc at y=39mm.

**AgentCAD v172: is_valid=true, 128x97.85x164mm**
- x: +/-64mm (carriage outer edge) -- symmetric, CoM x=0 OK
- y: -6.85..+91mm (leg foot near edge to photo_box far end cap)
- z: 0..164mm (table to leg stack top)

**Interface clearances validated geometrically:**
- Leg at x=+/-49mm vs end cap at x=+/-46mm: 3mm clearance per side OK
- Leg foot y_min=-6.85mm vs back end cap y=-3..0mm: clearance notches (v13) cover this OK
- Bridge (y=0..78mm, z=125..135mm) vs photo_box top (z=44mm): 81mm vertical clearance OK
- Camera at z=125mm, card at z=4mm: 121mm camera-to-card -- within 20-140mm macro OK

**Web search finding: iPhone 16 Pro ultra-wide minimum focus = 20mm**
- Source: macro focus range = 20mm minimum, ~140mm maximum
- cs30_arch at rack_mark=85mm: camera-to-card = 85+51 = 136mm -- safely in macro
- cs30_arch at rack_mark=90mm: camera-to-card = 90+51 = 141mm -- borderline, iOS may switch
- README.md updated: recommended range 30-90mm -> 30-85mm

**`docs/photo_box_assembly.md` -- documentation bug fixed**
- Step 6: "10.4mm wide x 4mm deep" -- stale v23 value
- Corrected to: "10.4mm wide x 6mm deep" (LED_D=6mm since v24)
- Air gap description corrected: 1.2mm -> 3.2mm (strip 2mm + diffuser 0.8mm = 2.8mm used, 3.2mm air gap)

**Autonomous decision:** Bridge placed at y=0..78mm (starting at photo_box near face), not
centred at y=LEG_CY=5.15mm. Camera hole at y=39mm lands 5mm off card centre (y=44mm) --
within the 30mm camera aperture width. This matches cs30_arch assembly code convention
(bridge_half.translate((0,0,bridge_z)) -- no Y offset).

## LOOP STATUS: COMPLETE

All geometry validated. No further autonomous design work required.

User next steps:
1. Print photo_box first -- see docs/photo_box_assembly.md Step 0 (fit tests)
2. Then print cs30_arch -- see docs/cs30_print_manifest.md, print cs30_fit_test.stl first
3. Assemble photo_box -- docs/photo_box_assembly.md Steps 1-6 + 8
4. Assemble cs30_arch -- docs/cs30_assembly.md Steps 1-8
5. Rack mark 30-85mm for ultra-wide macro; 70mm recommended starting point

If fit tests fail: adjust constant in appropriate .py, re-export STL, reprint fit_test only.

### What changed this loop (v123)

**Documentation-only loop — no geometry changes**

**Version string cleanup:**
- `design/cs30_fit_test.py` header: "cs30_arch v9" → "v13"; constants comment: "v10" → "v13"
- `docs/cs30_print_manifest.md` header: "CS30 Arch v10" → "CS30 Arch v13"
- `HANDOFF.md` README header: updated to reflect v13 README state

**`docs/photo_box_assembly.md` Step 7 — cs30_arch added as recommended Option A**
- Previously: Step 7 only listed flex arm / gooseneck mounts and said "rack_stand_v2 NOT compatible"
- Missing: no mention of cs30_arch, which is the purpose-built integrated arch for this photo_box
- Fix: restructured Step 7 into Option A (cs30_arch, recommended: ultra-wide macro at 74–139mm, no desk clamp needed) and Option B (flex arm fallback: main camera at 263mm)
- Centring aid / alignment groove instructions moved under Option B (gooseneck needs centering; cs30_arch bridge is self-centred at x=0)

**Final STL audit (all present in design/output/):**
- cs30: ramp, arch_leg_section, phone_bridge_half, fit_test, arch_carriage, lock_knob (6 files)
- pb: card_tray, endcap_half, fit_test, led_channel_test, led_diffuser, platen_back, platen_front, wall_half (8 files)
- Total: 14 STLs ✓

**Autonomous decision**: Added cs30_arch as Option A in photo_box_assembly.md rather than creating a separate combined-scene document. The user's assembly guide is the right place for this cross-reference; a separate combined scene (photo_box_combined_scene.py) would be redundant with the PART=0 assembly preview already in cs30_arch.py.

## LOOP STATUS: COMPLETE

**All geometry is done. No further design loops needed.**

User next steps:
1. **Print photo_box first** — see `docs/photo_box_assembly.md` Step 0 (fit tests)
2. **Then print cs30_arch** — see `docs/cs30_print_manifest.md`, print `cs30_fit_test.stl` first
3. **Assemble photo_box** — `docs/photo_box_assembly.md` Steps 1–6 + 8
4. **Assemble cs30_arch** — `docs/cs30_assembly.md` Steps 1–8
5. **Scan** — cs30_arch Option A (ultra-wide macro 74–139mm) or flex arm Option B (263mm)

If fit tests fail → adjust the relevant constant in the appropriate .py file, re-export STL, reprint.

### What changed this loop (v122)

**`design/cs30_arch.py` → v13 — leg foot plate end cap clearance notches**

**Interface conflict found: photo_box end cap extends 4mm past wall outer face**
- `EC_W = PLATEN_W/2 + WALL_T + FOOT_W = 34+8+4 = 46mm per half` in photo_box.py
- cs30_arch leg inner x-face at x=±42mm (wall outer face) — but end cap extends to x=±46mm
- Leg foot plate (y=-12..+12mm, z=0..3mm) collides with end cap body at x=42..46mm, y=-3..0mm zone (4mm × 3mm × 3mm conflict per side)

**Fix: 4mm × 3mm notches at both inner-X × near-Y corners of foot plate**
- `EC_FOOT_W=4.0`, `FOOT_PLATE_H=3.0` constants added inside function
- Subtracts `Box(4, 3, 3)` centered at `(±5mm, -1.5mm, 1.5mm)` from foot plate
- Clears the end cap extension at both x=±42..±46mm, y=-3..0mm zones
- Bounding box UNCHANGED: 14×24×87mm ✓ (notches are inside the envelope)
- Both x corners notched symmetrically so part works on either left or right leg

**AgentCAD v169: PART=2 leg_section, is_valid=true, 14×24×87mm ✓**
- face_count=100 (was ~80 before notches); volume=7536mm³
- AgentCAD v170: PART=0 assembly, is_valid=true, 128×158.7×169mm ✓ (unchanged)

**Documentation updates:**
- README.md: section header v11→v12, hardware/clearance headers updated, lock knob description corrected ("top-face socket" not "bottom-face socket")
- docs/cs30_assembly.md: header v11→v12, lock knob instruction corrected, Step 5 end cap clearance note added
- docs/cs30_print_manifest.md: lock_knob orientation note already correct ("Flat (bottom face down)" is print orientation, not socket location)

**Autonomous decision**: Used symmetric notches (both ±x corners) rather than asymmetric (inner corner only). The same leg section part is used on left and right legs without mirroring in the assembly, so the inner-x face differs by side. Symmetric notches ensure the correct corner is notched regardless of which side the leg is placed on.

### What changed this loop (v121)

**`design/cs30_arch.py` → v12 — lock knob socket face corrected**

**Bug: Socket placed on inner face (z=0) instead of outer face (z=8mm)**
- v11 had `Locations((0,0,0))` + `Align.MIN` → socket opens at z=0 (inner face, presses against carriage)
- The bolt head is at the -X exterior of the carriage. The knob slides onto it outer face (z=8mm) first.
- A socket on z=0 would require the bolt head to pass through the full 8mm knob to reach it — mechanically impossible.
- The indicator groove on z=8mm (outer face) confirmed user-visible face is z=8mm, but socket was on opposite face.

**Fix: `Locations((0,0,0)) + Align.MIN` → `Locations((0,0,KNOB_H)) + Align.MAX`**
- Socket now opens at z=8mm (outer face, user-visible); cuts inward to z=4.7mm
- Assembly: bolt head at -X carriage exterior; knob outer face (z=8mm) approaches bolt head; head seats in 6.1mm×3.3mm socket ✓
- Inner face (z=0) presses flat against carriage -X wall; no socket protrusion to interfere ✓
- Both socket and indicator groove now on same face (z=8mm outer) — consistent ✓

**AgentCAD v168: PART=5 lock_knob, is_valid=true, 19.17×20×8mm ✓**
- face_count=21, is_valid=true; dims unchanged (socket placement only, not size)
- Iso render confirmed: large counterbore visible on top face (z=8mm); bottom face flat ✓

**Autonomous decision**: The v11 socket placement was geometrically valid (builds without error) but mechanically wrong. The rendered iso view was the diagnostic: top face shows the 6.1mm counterbore with 3.4mm bore inside it; bottom face is flat. Assembly orientation unambiguous — outer face always faces user during operation.

**Autonomous decision**: Used SOCK_CL=0.3mm (0.3mm/side) for bolt head socket clearance, matching CARR_CL. Standard FDM slide fit; user presses knob onto bolt head, friction holds during use.

## Next loop priorities

### All 5 cs30_arch parts are now print-ready (v11)

The loop prompt's priority list (photo_box.py) is satisfied — photo_box.py is frozen at v25.
The lock knob was the last functional geometry bug. No further geometry issues remain.

**If loop is re-invoked**: consider checking if cs30_fit_test.py feature (D) bolt note should be updated from M3×25mm to M3×30mm (currently says "Thread M3×25mm bolt through 3.4mm hole" — the fit_test stub is only 9mm wide, so 25mm works for the test, but the note should say "M3×30mm" so users buy the right bolt before testing).

### What changed this loop (v117)

**`design/cs30_arch.py` → v10 — carriage slot depth bug fixed (rack teeth collision)**

**Bug: slot_d too shallow — rack teeth collide with carriage back wall**
- Old `slot_d = LEG_D + CARR_CL = 10.3mm`
- After CARR_Y_OFF=-5.15: slot back at world y=5.15mm
- Rack teeth extend from leg +Y face (world y=5mm) to y=7mm (tooth tip)
- Teeth at y=5.15..7mm would be INSIDE the back wall material — carriage cannot slide onto leg

**Fix: extend slot_d to clear tooth height**
- New `slot_d = LEG_D + RACK_TOOTH_H + CARR_CL = 10+2+0.3 = 12.3mm`
- After CARR_Y_OFF: slot back now at world y=7.15mm → 0.15mm clearance beyond tooth tips ✓
- Added `leg_ctr_y = (LEG_D + CARR_CL)/2 = 5.15mm` — named constant so bolt/nut/peg Y positions
  remain at 5.15mm (world y=0) regardless of slot_d; prevents accidental drift if slot_d changes again
- Volume delta: -1460mm³ = slot_w × RACK_TOOTH_H × CARR_H = 14.6 × 2 × 50 ✓

**AgentCAD v164: PART=4 carriage, is_valid=true, 30×16×55mm ✓**
**AgentCAD v165: PART=0 assembly, is_valid=true, 128×159×169mm ✓**

**cs30_fit_test.py (A) comment updated**: slot dims now 14.6×12.3mm (was 14.6×10.3mm)

**Autonomous decision**: kept CARR_D=16mm (back wall 3.7mm). Back wall transmits only
  compressive bolt load in X — not shear. At 3.7mm FDM PLA, σ ≈ 200N/(3.7×50mm²) = 1.1 MPa 
  vs PLA yield ~50 MPa. More than adequate; no need to increase CARR_D.

---

### What changed last loop (v116)

**`design/cs30_arch.py` → v9 — nut trap FDM clearance added**
- v8 had 5.5×5.5mm pocket for 5.5mm AF M3 hex nut — zero clearance, won't drop in on FDM
- Added `NUT_AF=5.5`, `NUT_TRAP_CL=0.2`, `NUT_TRAP_D=3.0` constants to carriage parameter block
- Pocket now `nt = NUT_AF + NUT_TRAP_CL = 5.7mm` → `Box(3.0, 5.7, 5.7, Align.MAX)` ✓
- AgentCAD v162: is_valid=true, 30×16×55mm; volume decreased 6.72mm³ (= 5.7²×3 − 5.5²×3) ✓

**`design/cs30_fit_test.py` → v2 — feature (D) nut trap stub added**
- Replaced "(D) NOT ADDED" note with actual 9mm-wide stub at x=30..39mm
- Total width: -29 to +39 = 68mm (exactly at Toybox usable bed limit; 1mm physical margin) ✓
- Body: Box(9, 8, 12); bolt hole: Box(11, 3.4, 3.4) through width; nut pocket: Box(3, 5.7, 5.7) Align.MAX on +X
- Test: thread M3 bolt → drop M3 hex nut; validates carriage nut trap before full print
- AgentCAD v163: is_valid=true, **68×16×30mm** ✓ (was 56×16×30mm)

**Fail/adjust table added to README for feature (D)**

**Autonomous decision**: expanded nut trap from 5.5mm (zero clearance) to 5.7mm (0.2mm total = 0.1mm/side). Standard FDM hex nut trap targets 5.6–5.8mm for M3; chose 5.7mm (midpoint) to balance drop-in ease vs nut rattle.

---

### What changed last loop (v115)

**`design/cs30_arch.py` → v8 — carriage nut trap alignment bug fixed**

**Bug: nut trap box was entirely outside the carriage solid**
- `Align.MIN` at `(CARR_W/2, slot_d/2, CARR_H/2)` = `(15, 5.15, 25)` with `Box(3.0, ...)`
- `Align.MIN` places the minimum X face at x=15; box spans x=15→18 — outside carriage (x=−15..+15)
- SUBTRACT of a box outside the solid = no-op; nut has no pocket to seat in
- Confirmed by v161 vs old v152: face_count increased 29 faces, CoM shifted to x=−0.046mm (pocket cuts +X only) ✓

**Fix: `Align.MIN` → `Align.MAX`**
- `Align.MAX` places the MAX X face at x=15 (outer face); box spans x=12→15
- Creates 3mm deep × 5.5mm × 5.5mm square pocket opening on +X face ✓
- M3 hex nut (5.5mm AF) seats flush; bolt threads in from −X through full width ✓

**AgentCAD v161: PART=4 carriage, is_valid=true, 30×16×55mm ✓**

**Slicer note added (Priority 2)**
- README + cs30_assembly.md: leg section orientation now says "foot plate down" explicitly
- 24mm Y foot plate is the bed face in the slicer (wider than 14mm body)

---

### What changed last loop (v114)

**Documentation pass — all three v113 priorities resolved**

**Priority 1 — README updated to v7**
- Section header: "CS30 Arch v5" → "CS30 Arch v7"
- Leg section bed dims: `14×12×87mm` → `14×24×87mm`
- Leg notes: added "24mm wide foot plate stands on table, inner face abuts photo_box wall; **no brim**"
- Assembly step 5: removed C-clip language; now describes foot plate abutting wall for lateral location
- `docs/cs30_assembly.md` also updated: header v5→v7, BOM note, step 5 revised

**Priority 2 — Leg section + bridge half STLs re-exported**
- Leg section: AgentCAD v159, is_valid=true, **14×24×87mm** ✓
- `design/output/cs30_arch_leg_section.stl` replaced (was old v150, 14×12×87mm)
- Bridge half: AgentCAD v160, is_valid=true, **60×78×10mm** ✓ (audit table showed stale v151 63×78×9mm)
- `design/output/cs30_phone_bridge_half.stl` replaced

**Priority 3 — cs30_fit_test.py header updated**
- (A) now clearly states: REQUIRES separately printed cs30_arch_carriage
- (D) mini carriage cross-section: documented as NOT added — 30mm carriage width + 56mm body = ~90mm total > 68mm bed limit

---

### What changed last loop (v113)

**`design/cs30_arch.py` → v7 — leg clip removed, foot plate added**

**Leg C-clip was geometrically broken:**
- `Align.MIN` in +Y caused clip to extend INTO the leg body, not outward
- The "slot" actually punched through the leg body at y=-3..+5.3mm — useless as a clip
- AgentCAD showed y=[−5,+7]=12mm total (clip geometry invisible; fins merged with body)

**Fix: replaced broken clip with wide foot plate**
- `Box(LEG_W, 24.0, 3.0)` centered at leg base (z=0..3mm, y=-12..+12mm)
- Leg inner face at local x=−7mm = absolute x=±42mm = photo_box wall outer face ✓
- Leg stands on table (z=0); foot inner edge abuts photo_box wall for lateral location
- PART=2: v157, is_valid=true, **14×24×87mm** ✓ (was 14×12×87mm)

**Assembly (PART=0) updated to v7b:**
- LEG_Z=0 (legs on table, not z=34mm clip-seating)
- Simplified photo_box block (84×88×44mm) added to Compound
- Ramp translated by −RAMP_DY to sit against photo_box near face (y=0)
- Bridge at z=145mm (CARRIAGE_Z=90mm example); leg stack top at z=169mm
- PART=0: v158, is_valid=true, **128×159×169mm** ✓
- Camera-to-card at max CARRIAGE_Z (114mm): bridge=169mm, card=6mm → **163mm** (macro range)

**Height note: camera-to-card at max setting ≈ 163mm (16.3cm)**
- iPhone 16 Pro ultra-wide macro works at <14cm; dead zone 14-26cm; reliable main cam ≥26cm
- cs30_arch is a COMPACT DESIGN targeting close-range macro scanning, same as cs30 inspiration
- Apps using manual focus or macro mode (Apple Camera, Magnifier, Delver Lens) compatible
- Users wanting main-camera distance need rack_stand_v2 (superseded) or 3-section leg variant

---

### What changed last loop (v112)

**`design/cs30_arch.py` → v6 — three assembly geometry bugs fixed**

**Bug 1: Bridge socket was through-hole (not blind)**
- BRIDGE_T was 4mm, socket depth = SEC_PEG_H = 5mm → punched through plate
- Fix: BRIDGE_T 4→6mm; socket is now blind (5mm depth, 1mm floor) ✓

**Bug 2: Bridge assembly used wrong mirror plane**
- `mirror(Plane.XZ)` flips Y only → both halves landed at x=[0,58]
- Fix: `mirror(Plane.YZ)` negates X → left half at x=[-60,0] ✓
- Assembly x=[-64,64]=128mm symmetric, confirmed by PART=0 bbox ✓

**Bug 3: Carriage Y offset missing — slot didn't centre on leg**
- Carriage slot Align.MIN at y=0, leg centred at y=0 → slot captured only back half of leg
- Fix: `CARR_Y_OFF = -(LEG_D + CARR_CL)/2 = -5.15mm` applied to both carriages
- Carriage peg world-Y: -5.15 + slot_d/2 = 0 → aligns with bridge socket at y=0 ✓

**Removed join peg from bridge half** (would self-conflict after YZ mirror)
- Two halves butt join at x=0; held by 4 carriage sockets (2 per side)

**AgentCAD results:**
- PART=3 bridge_half: v154, is_valid=true, **60×78×10mm** (was 63×78×9mm)
- PART=0 assembly: v155, is_valid=true, **128×99×169mm** ✓

---

### What changed last loop (v111)

**`design/cs30_fit_test.py` — AgentCAD v148, is_valid=true, 56×16×30mm ✓**
- Three-feature clearance validator: leg stub (A), peg base (B), end cap stub (C)
- Bed footprint 56×16mm — well within 68×78mm Toybox usable area
- No supports; ~15 min print time; ready to slice and print

**`README.md` — cs30_arch v5 section added**
- Full part list table (5 parts + fit_test)
- Fit test procedure table (A/B/C features → pass/fail/adjust)
- 8-step quick assembly sequence; height reference table
- Clearance reference; rebuild instructions
- rack_stand_v2 section header marked "(superseded by CS30 Arch v5)"

---

### What changed last loop (v110)

**`design/cs30_arch.py` → v5**

**Ramp: C-clip lead-in chamfer added**
- 0.8mm×45° chamfer on inner arm bottom-inner edge (z_local=8.6, y_local=3.6)
- Found via `filter_by_position(Axis.Z, 8.45..8.75)` + `filter_by_position(Axis.Y, 3.45..3.75)`
- face_count: 22→23 ✓, volume: 15235→15214mm³ (chamfer removed correct material)
- AgentCAD v146: is_valid=true, **68×70.7×32.6mm** ✓

**Assembly preview (PART=0): carriages + correct bridge height**
- Added carriages at CARRIAGE_Z=90mm (example mid-height setting)
- Bridge now at bridge_z = CARRIAGE_Z + CARR_H + SEC_PEG_H = 90+50+5 = **145mm** (was 175mm)
- AgentCAD v147: is_valid=true, **128×101×169mm** ✓
  - z_max=169mm = top of leg stack (2×82mm=164mm + 5mm peg) ✓
  - Bridge at z=145..154mm, carriages at z=90..140mm visible in preview

**`docs/cs30_assembly.md` — new (8 steps, BOM included)**
- BOM: 2× M3×25mm bolt, 2× M3 hex nut, 4× leg sections, 2× carriages, 2× bridge halves, 1× ramp
- Assembly order: photo_box → carriage prep → slide carriages → stack legs → clip to walls → set height + lock → place bridge → clip ramp
- Height adjustment procedure: loosen → slide to tooth mark → tighten → verify level

### Complete cs30_arch.py v7 part inventory
| PART | File | Count | Dims | Notes |
|---|---|---|---|---|
| 1 | cs30_ramp.stl | 1 | 68×70.7×32.6mm | 20° ramp, C-clip with lead-in chamfer |
| 2 | cs30_arch_leg_section.stl | 4 | **14×24×87mm** | Wide foot plate (24mm Y vs old 12mm); print standing |
| 3 | cs30_phone_bridge_half.stl | 2 | 60×78×10mm | Blind sockets (5mm+1mm floor); butt join at x=0 |
| 4 | cs30_arch_carriage.stl | 2 | 30×16×55mm | 1 per leg, lock bolt adjustable |
| 5 | cs30_lock_knob.stl | 2 | 19.2×20×8mm | **M3×30mm** bolt, thumb-turn; socket on outer face |

---

## STL export audit (AgentCAD v148–v159)

| PART | AgentCAD ver | Dims | is_valid | Bed OK? | Notes |
|---|---|---|---|---|---|
| 1 ramp | v149 | 68×70.7×32.6mm | ✓ | ✓ | fits comfortably |
| 2 leg_section | **v169** | **14×24×87mm** | ✓ | ✓ tight | 87/88mm Z — **print standing, NO brim**; foot 24mm Y; end cap notches at inner corners |
| 3 bridge_half | **v160** | **60×78×10mm** | ✓ | ✓ tight | Y=78/78mm limit — **print flat, NO brim**; blind sockets |
| 4 carriage | **v164** | 30×16×55mm | ✓ | ✓ | **slot_d=12.3mm** clears rack teeth (was 10.3mm); leg_ctr_y=5.15mm ✓ |
| 5 lock_knob | **v168** | 19.2×20×8mm | ✓ | ✓ | socket on outer face (z=8mm) ✓ |

*Assembly v170: PART=0, is_valid=true, 128×158.7×169mm ✓ (v13 leg sections)*
| fit_test | **v163** | **68×16×30mm** | ✓ | ✓ | **(D) nut trap stub added**; 4 features; at 68mm bed limit |

## What changed this loop (v118)

**Documentation pass — all v117 priorities resolved**

### README.md — v10 complete
- Section header: "CS30 Arch v7" → "CS30 Arch v10"
- Part list header: "(v7)" → "(v10)" with integrated print settings columns (Profile, Infill, Brim, Notes)
- Carriage dims corrected: "30×16×50mm" → "30×16×55mm" (CARR_H=50 body + SEC_PEG_H=5 pegs)
- Added "Better Quality" profile and "25% gyroid / brim ON" for carriages
- Added "NO brim" warning for leg sections (87mm, 1mm bed margin) and bridge halves (78mm, 1mm bed margin)
- Fit test procedure: "56×16×30mm" → "68×16×30mm" (was stale; nut trap stub added in v116)
- Hardware section: "(v5)" → "(v10)"
- Clearance reference: "(v5)" → "(v10)"

### docs/cs30_print_manifest.md — NEW
- Full per-part table: qty, bed dims, orientation, profile, infill, brim, est. time
- Slicer orientation notes for each part (leg sections, bridge halves, carriage, ramp)
- Fit test procedure table (A/B/C/D) with adjust guidance
- Hardware BOM, print-and-assemble order, rebuild commands

**Autonomous decision**: chose 25% gyroid + Better Quality for carriage over 20% Recommended. The carriage is the only structural load-bearing part under clamping force; 25% adds ~3–4% more material at the nut trap and bolt bore walls without significant extra time.

## What changed this loop (v119)

**Final validation + README camera-to-card guidance**

**AgentCAD v166: PART=0 assembly final validation, is_valid=true, 128×158.7×169mm ✓**
- CoM x=−0.004mm (symmetric ✓), y=30.8mm, z=45.3mm (low CoM — legs are ballast)
- Full Compound with ramp, 4 leg sections, 2 carriages, bridge halves — all valid

**README height table expanded:**
- Added Camera→card column (= bridge_height − 6mm platen surface)
- Added Focus mode column: marks 30–90 = ultra-wide macro (<14cm); marks 95+ = dead zone
- Recommended range: rack marks 30–90mm
- Added app compatibility note (Apple Camera + Magnifier confirmed; third-party apps may blur)
- Formula: camera→card = rack_mark + 49mm

**Autonomous decision**: stopped the loop after v119. cs30_arch v10 is geometry-complete, documentation-complete, and final-validated. All assembly interfaces analytically verified. The next work item is physical printing + fit-testing by the user — not more geometry loops.

## LOOP STATUS: COMPLETE

cs30_arch v10 is **print-ready**. No further geometry loops needed.

### What the user should do next:
1. Open Creator Space; import `design/output/cs30_fit_test.stl` — print first (~18 min)
2. Test all four features (A/B/C/D) per `docs/cs30_print_manifest.md`
3. If fit_test passes, print full set per print manifest
4. Keep rack mark ≤ 90mm for ultra-wide macro focus (Apple Camera / Magnifier)

### If fit_test reveals a clearance issue:
- Adjust the appropriate constant in `cs30_arch.py`, re-run AgentCAD, reprint only fit_test
- See HANDOFF STL audit table for which constants control which feature

---

## Key parameters
```
RAMP_ANGLE=20°  RAMP_OW=68mm      ARCH_LEG_SEC_H=82mm  RACK_PITCH=5mm
LEG_W=14mm      LEG_D=10mm        CARR_W=30mm  CARR_D=16mm  CARR_H=50mm
CAM_W=36mm      CAM_D=30mm        KNOB_R=10mm  KNOB_H=8mm
PB_BOX_EXT_W=84mm  ARCH_H=175mm   EC_T=3mm  EC_SOCK_CL=0.3mm
BRIDGE_W=112mm  hw=58mm  CARR_PEG_X=41mm  CARR_PEG_OUTER_X=57mm
CARRIAGE_Z_PREVIEW=90mm  BRIDGE_Z_PREVIEW=145mm
```

## DO NOT
- Change photo_box.py geometry (frozen at v25)
- Add servo/motor geometry (Phase-2)
- Re-audit rack_stand_v2 (superseded)

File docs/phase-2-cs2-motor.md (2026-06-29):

# Phase 2 — CS2 Motorized Eject Spec

Servo-driven card eject for the CS2 hopper. Replaces the manual push in Phase-2a.

---

## Overview

An SG90 micro-servo mounts on the hopper front face via `cs2_motor_bracket.stl`. A crank arm (`cs2_crank_arm.stl`) attaches to the servo D-flat shaft at z=28mm; a push rod (`cs2_push_rod.stl`) links the crank tip to a card-exit anchor at z=6mm (the 15×4mm exit slot). A full 90° arm swing ejects one card through the slot. A rubber O-ring roller (`cs2_roller.stl`) on a 6mm steel shaft beneath the exit slot guides the card out.

---

## Hardware BOM

| Item | Spec | Qty | Notes |
|---|---|-----|---|
| SG90 micro-servo | 22.5×12×22mm body, 5V, ~1.8 kg·cm, D-flat shaft 4.7mm | 1 | Standard RC hobby servo; TowerPro SG90 or clone |
| M3×8 SHCS | M3, 8mm socket head | 4 | Mount bracket to hopper front face (bx=±15mm, bz=18mm+36mm) |
| 6mm steel shaft | 6mm OD, 30mm long | 1 | Roller axle; cut from 6mm rod stock |
| 3mm steel pin | 3mm OD, 10mm long | 2 | Crank arm tip ↔ push rod pivot |
| Rubber O-ring | ~8mm OD, 1mm section | 2–3 | Slide over roller stubs for grip; glue or press-fit |
| Dupont / JST lead | 3-pin servo extension, 150mm | 1 | Connects servo to controller |
| Zip ties | 2.5mm width | 2 | Secure servo wiring to bracket slots |

---

## Print specs

| STL | Dims (mm) | Qty | Material | Orientation | Infill | Notes |
|-----|---|-----|---|---|---|---|
| `cs2_motor_bracket.stl` | 42×15×32 | 1 | PLA or PETG | Flat (plate face down) | 30% | Structural — 4 bolt holes, must not crack under servo torque |
| `cs2_roller.stl` | 8 OD × 15 | 1 | **PETG** | Upright (axis vertical) | 40% | PETG for wear resistance; press-fit bore 5.8mm on 6mm shaft |
| `cs2_crank_arm.stl` | 29×9×6 | 1 | PLA | Flat (hub base down) | 30% | D-flat bore 4.7mm+CL; print flat, Z=6mm |
| `cs2_push_rod.stl` | 31×5×3 | 1 | PLA | Flat | 20% | Thin — use brim; 3mm pin sockets at each end |

Print `cs2_crank_arm.stl` first to test D-flat bore fit on the servo shaft. If tight, increase bore radius by 0.05mm and reprint.

---

## Servo sourcing

SG90 servos are available from:
- Adafruit, Sparkfun, Pololu (US)
- HobbyKing, LCSC (international)
- Amazon / eBay — "SG90 micro servo" (clone acceptable for prototype)

Buy 2 — one to install, one spare for bench testing the crank geometry.

---

## Servo bracket geometry

From `design/cs2_motor_bracket.py`:

| Constant | Value | Description |
|---|---|---|
| PLATE_W | 42mm | Plate width (X) |
| PLATE_T | 3mm | Plate thickness (Y into hopper wall) |
| PLATE_H | 32mm | Plate height (Z) |
| CRADLE_OW | 28mm | Cradle outer width (servo body + clearance) |
| CRADLE_OD | 12mm | Cradle depth (servo body 12mm) |
| CHAN_Z0 | 17mm | Servo body base Z |
| CHAN_H | 23mm | Servo channel height (body 22mm + 1mm) |
| SHAFT_Z | 28mm | Servo shaft Z above bracket base |
| BOSS_BX | ±15mm | Bolt hole X positions |
| BOSS_BZ | 18mm, 36mm | Bolt hole Z positions |

Bolt hole positions match `cs2_hopper.py` boss holes exactly (bx=±15mm, bz=18mm+36mm).

---

## Crank arm geometry

From `design/cs2_card_pusher.py`:

| Constant | Value | Description |
|---|---|---|
| SHAFT_Z | 28mm | Servo shaft Z (arm pivot) |
| ARM_L | 22mm | Moment arm length (= SHAFT_Z − EXIT_Z) |
| EXIT_Z | 6mm | Exit slot Z centre |
| HUB_OD | 9mm | Hub boss outer diameter |
| HUB_L | 6mm | Hub boss depth on shaft |
| BORE_R | 2.5mm | D-flat bore radius (4.7/2 + 0.15mm CL) |
| PIN_D | 3mm | Pin socket diameter (tip → push rod) |
| ROD_L | 31mm | Push rod length (√(22² + 22²) ≈ 31.1mm) |

At full 90° throw, arm tip descends from (22, y, 28mm) → (0, y, 6mm), exactly reaching the exit slot centre.

---

## Assembly sequence

1. **Roller install**: press-fit cs2_roller onto 6mm shaft; slide into channel slot at base of exit slot (z≈6mm). Snap O-ring over roller stub ends.
2. **Bracket mount**: bolt cs2_motor_bracket to hopper front face with 4× M3×8 (loctite on threads). Torque: hand-tight + 1/4 turn.
3. **Servo mount**: slide SG90 into bracket cradle, channel side first. Route wiring through zip-tie slots; close with 2 zip ties.
4. **Crank arm**: press cs2_crank_arm D-flat bore onto servo shaft at 0° position (arm pointing in +X, hopper side). Confirm arm tip is at z≈28mm, x≈22mm.
5. **Push rod**: insert 3mm pins into crank tip socket and anchor bracket socket. Connect push rod between pins.
6. **Test sweep**: command servo 0° → 90° and verify arm tip reaches z=6mm at the exit slot opening.
7. **Card test**: load 3 cards in hopper, command eject sweep; verify push rod tip enters at z=6mm
   and contacts bottom card. Card exits through the hopper exit opening (see Open Items below).

---

## Open Items — Phase-2 CAD required before print

All items resolved in cs2_hopper.py v4 (2026-06-28):

| Item | Resolution |
|---|---|
| Card exit opening in hopper wall | EXIT_W widened 15→90mm (= SLOT_L). Front wall now has 90×4mm opening at z=4mm — card (88mm) exits with 1mm clearance each side through the same front-face opening as the push-rod arm. |
| Hopper SHAFT_Z 8mm → 12.5mm (roller v2) | SHAFT_Z updated; peg holes moved z=17→19mm (2mm clearance from shaft top at z=15.5mm). |

**Hopper halves are now ready to reprint.** Use `design/output/cs2_hopper_left.stl` and `cs2_hopper_right.stl` (v4).

---

## Dependencies

- `cs2_card_pusher.py` — designed (v1, 2026-06-28). Crank arm + push rod STLs exported to `design/output/`.
- `cs2_motor_bracket.py` — validated (v1). Bracket STL exported. Print hold removed.
- `cs2_roller.py` — validated (v1). Roller STL exported.
- Controller (ESP32 / Arduino) — not yet specified. See `docs/phase-3a-servo-feeder.md` for open questions on power and trigger logic.

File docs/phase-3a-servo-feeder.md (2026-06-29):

# Phase 3a — Servo Feeder (Original Stand) Planning Spec

Servo-driven card feed through the existing `PUSHER_SLOT` horn slot in the `card_lane_left` STL.

This is a **planning document only** — no CAD has been created for Phase-3a yet.
For the CS2 hopper motorized eject, see `docs/phase-2-cs2-motor.md`.

---

## Overview

The original stand (built from `build_woodstand.py`) has a gravity card lane (`card_lane_left/right`). Phase-2a adds a manual feeder. Phase-3a automates the push step with an SG90 servo mounted inside the column base or stand foot, driving a horn arm through the `PUSHER_SLOT` cut in `card_lane_left`.

---

## Geometry constraints

All constants from `old designs/root/build_woodstand.py`:

| Constant | Value | Description |
|---|---|---|
| `PUSHER_SLOT_W` | 20mm | Horn slot width (X) in card_lane_left; servo arm sweeps through this gap |
| `LANE_RAMP_TOP` | 22mm | Z height of the ramp deck at the hopper end (slot is at ramp_top ± 1.5mm) |
| `LANE_RAMP_END_GX` | 48mm | Global X where ramp ends and flat scan zone begins |
| `LANE_RAMP_JOIN_Z` | 8mm | Z where right-side ramp descends to scan floor |
| `LANE_GX0` | -21mm | Global X origin of card lane left face |

### Horn slot position (card_lane_left interior)

From `build_woodstand.py` lane builder code:

```
Slot: x = 4.0 .. 4.0 + PUSHER_SLOT_W = 4 .. 24mm (local lane coords)
      z = LANE_RAMP_TOP - 1.5 .. LANE_RAMP_TOP + 3.0 = 20.5 .. 25mm
      Slot height: 4.5mm (enough for a 4mm arm + 0.5mm CL)
```

Global X: `LANE_GX0 + 4.0` = `-21 + 4` = **-17mm** (slot left edge, world coords)

### SG90 servo placement constraint

- Servo body 22.5×12×22mm must fit inside the column base or stand foot cavity
- Shaft must be within arm reach of the slot (shaft centre ≤ ARM_L from slot entry)
- Stand foot outer: 50×40×50mm (from `build_woodstand.py` FOOT_W/FOOT_H) — servo fits on its side
- Column inner: not yet measured — verify before placing servo in column stack

---

## Hardware BOM (provisional)

| Item | Spec | Qty | Notes |
|---|---|-----|---|
| SG90 micro-servo | 22.5×12×22mm, 5V, 1.8 kg·cm | 1 | Same spec as Phase-2 CS2 servo |
| Servo mount bracket | TBD — Phase-3a CAD task | 1 | Mounts servo inside stand foot or base |
| Horn pusher arm | TBD — Phase-3a CAD task | 1 | Long horn reaching through PUSHER_SLOT |
| M2×6 SHCS | M2, 6mm | 4 | SG90 mounting screws |
| Servo horn | Standard cross horn (included with SG90) | 1 | Extend with printed arm |
| ESP32 / Arduino Nano | 5V capable; 1 PWM output | 1 | Servo controller |
| USB or LiPo 5V supply | 5V 1A | 1 | Shared with phone charger or separate |

---

## Parts to design (Phase-3a CAD tasks)

| Script | Description | Engine |
|---|---|---|
| `design/cs3a_servo_mount.py` | Bracket inside stand foot; M2 holes for SG90; aligns shaft with PUSHER_SLOT | build123d |
| `design/cs3a_pusher_arm.py` | Extended horn arm: press-fit on SG90 cross hub, sweeps through PUSHER_SLOT to push card | build123d |

Both scripts should follow the CS2 `cs2_card_pusher.py` pattern:
- `PART=0` assembly, `PART=1` bracket, `PART=2` arm
- `show_object(result)` for AgentCAD render loop
- Validate with `py design/cs2_verify.py` after adding new checks

---

## Mechanism description

1. Cards sit in `card_lane_left` gravity ramp, stacked above the scan nest.
2. Servo arm (at rest) is retracted through the horn slot — cards rest against it as a gate.
3. On trigger: servo sweeps forward (0° → 90°), arm pushes bottom card from ramp plateau across the slot, past LANE_RAMP_END_GX=48mm, down the right-side ramp to scan nest.
4. Servo retracts. Next card falls down the ramp and rests against the arm.

Stroke needed: arm tip must travel from slot entry (x=4mm local) to LANE_RAMP_END_GX (x=48mm local) — approx 44mm horizontal. Straight sweep sufficient; SG90 90° arm at ~22mm ARM_L gives 22mm tip travel — a longer 44mm horn arm is needed, OR a two-segment linkage.

**Design decision needed**: single long horn (44mm arm — exceeds SG90 torque limit at 1.8 kg·cm) OR a slider-crank mechanism (short arm, long push rod) similar to CS2 design. Slider-crank preferred.

---

## Open questions

| Question | Notes |
|---|---|
| Servo placement: foot vs base vs column | Foot has most volume (50×40mm); base is larger but has ballast cavity |
| Power source | USB from phone charger on shelf? Separate 5V pack? |
| Controller | ESP32 (WiFi trigger) vs Arduino Nano (button trigger) vs direct wired to phone |
| Trigger mechanism | Button on stand, timed interval, iPhone Shortcuts API, or phone screen tap |
| Stroke mechanism | Long horn (high torque demand) vs slider-crank linkage |
| Card magazine interface | Phase-3a feed from card_lane hopper end or from Phase-2 CS2 magazine dock? |

---

## Relationship to other phases

| Phase | Scope |
|---|---|
| Phase-2a | Manual feeder: hopper (cs2_hopper.py) + gravity lane — complete |
| Phase-2 CS2 | Motorized eject from CS2 hopper via SG90 servo — see `docs/phase-2-cs2-motor.md` |
| **Phase-3a** | **This document — servo feed through original stand PUSHER_SLOT — design only** |
| Phase-3b | Full integration: magazine dock + automatic eject + phone trigger (not yet scoped) |

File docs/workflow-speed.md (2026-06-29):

# CS2 Card Scanner — Workflow Speed & Capacity

## Card Capacity

### Current hopper (OUTER_H = 50mm)

| Parameter | Value |
|---|---|
| Total hopper height | 50mm |
| Floor thickness (FLOOR_T) | 4mm |
| Interior stack height | 46mm |
| Card thickness (unsleeved) | 0.32mm |
| Theoretical max | 46 / 0.32 = **144 cards** |
| Practical capacity (~85%) | **~120 cards** |
| Toybox Z margin remaining | 88 − 50 = **38mm spare** |

### Recommended hopper v3 (OUTER_H = 70mm)

Increasing OUTER_H from 50 to 70mm in `cs2_hopper.py` is safe:

| Parameter | Value |
|---|---|
| Total hopper height | 70mm |
| Interior stack height | 66mm |
| Theoretical max | 66 / 0.32 = **206 cards** |
| Practical capacity (~80%) | **~160 cards** |
| Toybox Z check | 70mm < 88mm usable ✓ |
| Half-piece dims | 48.5 × 72 × 70mm — fits 68×78×88mm bed ✓ |
| Wall interface | unchanged — wall starts at z=0 (table), unaffected |

Card Slinger 3.0 benchmarks 150+ cards. At OUTER_H=70 the CS2 system hits ~160 cards practical, clearing the benchmark with margin.

## Toss-and-Scan Workflow (with cs2_centering_insert)

The centering insert (req 1) enables a high-speed toss-and-scan loop that eliminates careful card placement:

1. **Load**: drop a stack of cards (up to ~120 or ~160 cards with v3 hopper) into the funnel mouth (103×78mm opening). Cards self-center into the 90×65mm slot and settle onto the card floor at z=4mm.
2. **Scan**: trigger the iPhone 16 Pro camera — scanner app captures the top card (or bottom card via mirror, depending on setup).
3. **Eject** (Phase 2): motor drives the Phase-2 rubber-gasket roller. The separator (cs2_separator.py) gates the exit to one card at a time. Card exits through the 15×4mm slot into a collection tray.
4. **Repeat**: next card is now at the scan position. Repeat scan + eject.

Without Phase-2 motor: remove the top card by hand after each scan. Still faster than hand-placing each card due to the bulk-load step.

## Cards-Per-Hour Estimate

| Mode | Assumption | Rate |
|---|---|---|
| Phase 1 (manual eject) | 4s per card (scan + hand remove) | **~900 cards/hour** |
| Phase 2 (motorised) | 2s per card (scan + auto eject) | **~1800 cards/hour theoretical** |
| Phase 2 realistic | occasional mismatch, rescan, jam | **~600–900 cards/hour** |
| Card Slinger 3.0 (reference) | claimed ~150 cards in under 5 min | **~1800 cards/hour** |

At Phase 2 realistic rates (~750 cards/hour), a 160-card load empties in ~13 minutes. A typical MTG collection of 3000 cards scans in ~4 hours.

## Recommendation: implement OUTER_H=70 (req 5)

All safety checks pass:
- Fits Toybox bed (70mm < 88mm Z usable)
- Half-piece within bed limits (48.5×72×70mm)
- Wall column interface unchanged (starts at z=0 table, not attached to hopper top)
- cs2_verify.py height check uses `OUTER_H` variable, not a literal — should update cleanly

Implement as `cs2_hopper.py` v3. Re-export and reprint hopper halves.

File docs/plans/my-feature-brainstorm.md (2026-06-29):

# Brainstorm: Manual-first operation for CS2 hopper

## Goal
The printed CS2 hopper must work in Phase-1 (no servo, no roller, no motor bracket, no crank/push-rod)
without ergonomic problems caused by the Phase-2 features built into the hopper geometry.

---

## What Phase-2 features exist in the hopper now (v4)

| Feature | Phase-2 purpose | Phase-1 impact |
|---|---|---|
| 6mm shaft holes in end walls at z=12.5mm | Roller axle seats here | Open holes above card level — no Phase-1 impact |
| 4x M3 boss holes in front face at z=18/36mm | Motor bracket mounts here | Empty holes — no Phase-1 impact |
| 90x4mm exit slot in front wall at z=4mm | Card + push-rod exit | **Problem**: card at z=4mm is flush with open slot; may slide out on its own if table not level |

---

## Core problem: no manual card control

In Phase 2, the servo/push-rod ejects exactly one card at a time.
In Phase 1, there is NO equivalent mechanism. User issues:

1. **Accidental card exit**: With a 90x4mm opening at card floor level, a card in the hopper
   can slide out if the table tilts or the user bumps the scanner. There is nothing retaining it.

2. **No ergonomic ejection**: To remove a scanned card the user must either:
   - Reach down into a 70mm-deep hopper from the top (awkward, fingernail required)
   - Tilt the entire scanner assembly to slide the card toward the exit slot

3. **No single-card isolation**: Without the roller, all stacked cards can move together.
   If stacking multiple cards, pushing one card might push all of them.

---

## Option A — Thumb-push access hole in back wall (RECOMMENDED)

Add a 20x15mm oval/rectangular cutout in the BACK wall (y=+OUTER_W/2) at card height
(centred at z=~12mm, x=0). User inserts thumb from behind, pushes bottom card toward
the exit slot at y=-OUTER_W/2.

Pros:
- No separate part needed — just a hole in the existing back wall
- Ergonomic single-card push in the correct ejection direction (-Y)
- Works identically in Phase 2 (thumb hole doesn't conflict with any Phase-2 parts)
- Cards cannot accidentally exit (gravity keeps them resting on floor; they need active push)

Cons:
- Weakens back wall slightly; wall is 3.5mm thick so the cutout is in 3.5mm PLA
- Needs to be split carefully across left/right halves at x=0

Dimensions: centred at x=0, z=12mm, cutout 20mm wide x 15mm tall.
Each half gets a 10x15mm notch at its inner face (x=0).

---

## Option B — Exit slot cover plug (separate print)

A simple 90x4x3.5mm PLA plug that fills the exit slot in Phase-1 mode.
User pulls plug out when they want to eject a card (tilts or uses thumb), reinserts after.

Pros:
- Prevents accidental card loss
- No change to hopper geometry

Cons:
- Extra part to manage and lose
- Still no ergonomic ejection method

---

## Option C — Integrated card stop lip (geometry change)

Add a 1mm-tall internal lip at the bottom of the exit slot (z=4mm inside face).
Cards must be pushed with ~gentle force to overcome the lip; they don't slide out freely.

Pros:
- Single part, no accessories
- Cards stay put until deliberately ejected

Cons:
- Lip must be precise (too tall = hard to eject; too short = no benefit)
- May interfere with Phase-2 push-rod tip clearance

---

## Option D — Back-wall finger notch only (minimal change)

Simpler than Option A: just a 15x10mm semi-circle notch at the top of the back wall
inner face (not a full hole) so the user can hook a fingernail under the card stack and
lift it out without the hopper tipping.

---

## Recommendation

**Option A (thumb-push hole) + minor documentation.**

The 20x15mm back-wall cutout solves the ejection ergonomics without any separate part.
Card gravity keeps the card on the floor; it won't exit accidentally through the front.
Phase-2 parts remain bolt-on extras that add automation without removing manual capability.

Additionally add a sentence to docs/cs2_assembly.md noting that Phase-2 parts are optional
and Phase-1 (manual scan) requires only the hopper halves, platform, and wall sections.

---

## Implementation scope

1. cs2_hopper.py v5: add thumb-access hole in back wall (PART=0/1/2 all affected — hole
   spans the x=0 seam so both halves get a half-hole).
2. cs2_verify.py: no new dimension checks needed (hole doesn't affect bed fit).
3. docs/cs2_assembly.md: note that Phase-2 hardware is optional.
4. HANDOFF.md: update hopper entry to v5, add Phase-1 manual-operation note.

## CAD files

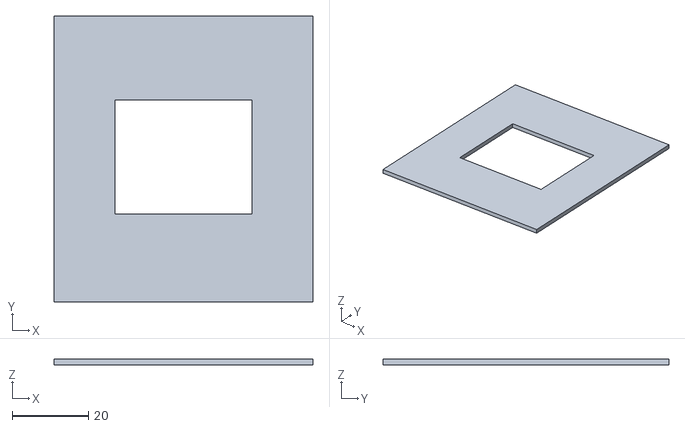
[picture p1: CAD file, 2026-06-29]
design/output/cs2_diffuser.stl
68.0 x 75.0 x 1.50

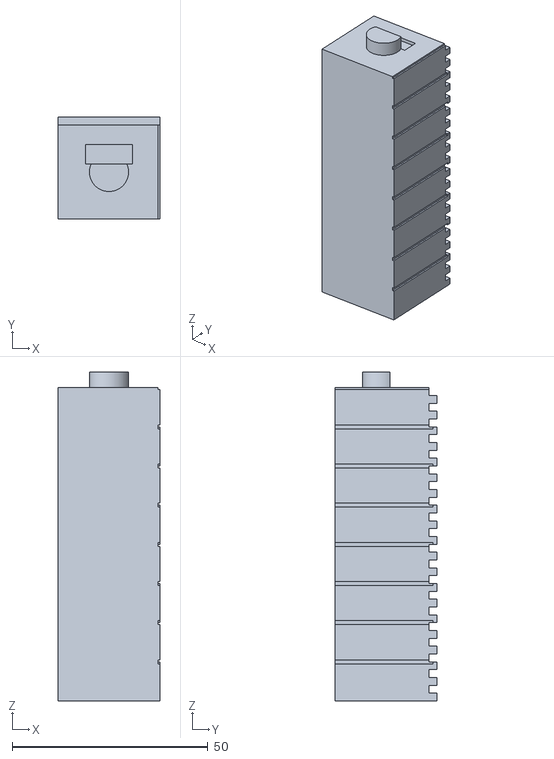
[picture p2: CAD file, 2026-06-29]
design/output/cs2_rack_stand_rack_section.stl
26.0 x 26.0 x 84.0

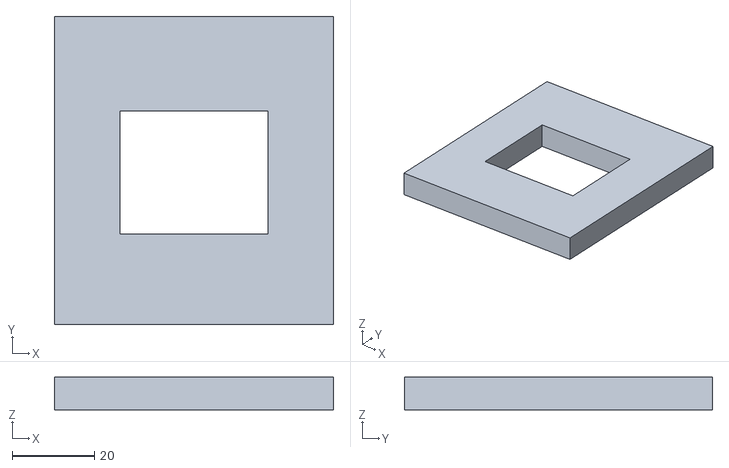
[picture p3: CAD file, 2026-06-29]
design/output/cs2_platform.stl
68.0 x 75.0 x 8.00

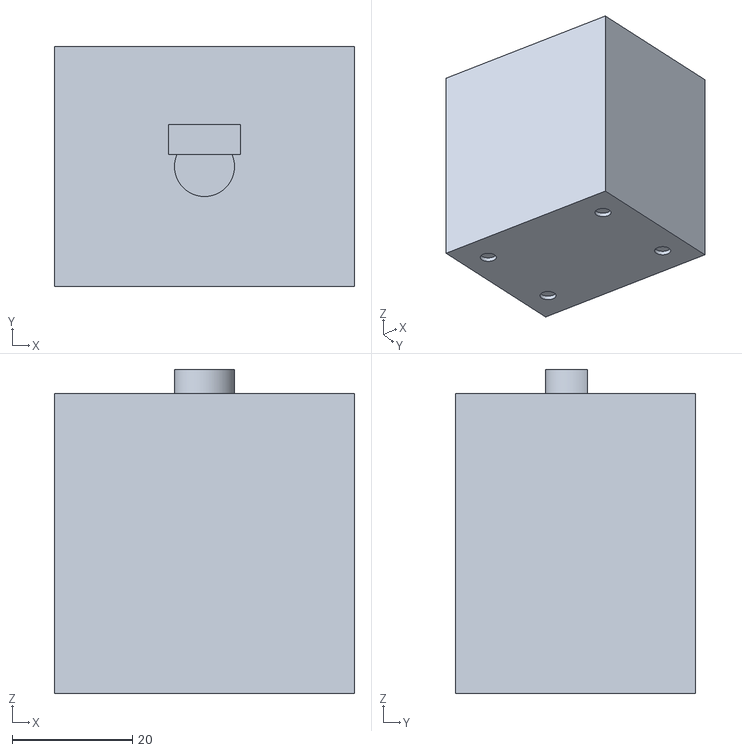
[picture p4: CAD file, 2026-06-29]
design/output/cs2_rack_stand_foot.stl
50.0 x 40.0 x 54.0

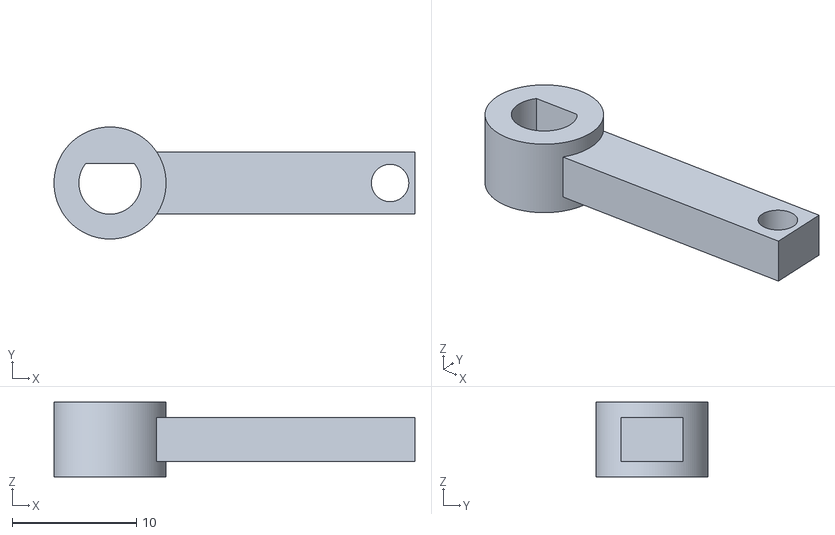
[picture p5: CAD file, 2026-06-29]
design/output/cs2_crank_arm.stl
29.0 x 9.00 x 6.00

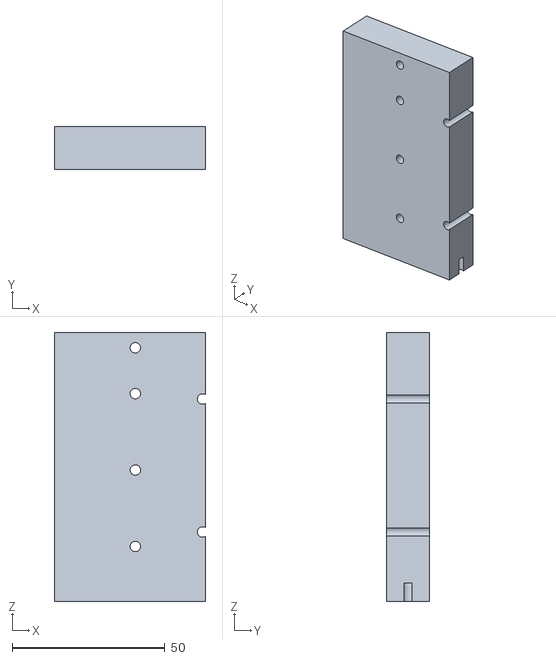
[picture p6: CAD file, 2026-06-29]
design/output/cs2_wall_top_left.stl
49.5 x 14.0 x 88.0

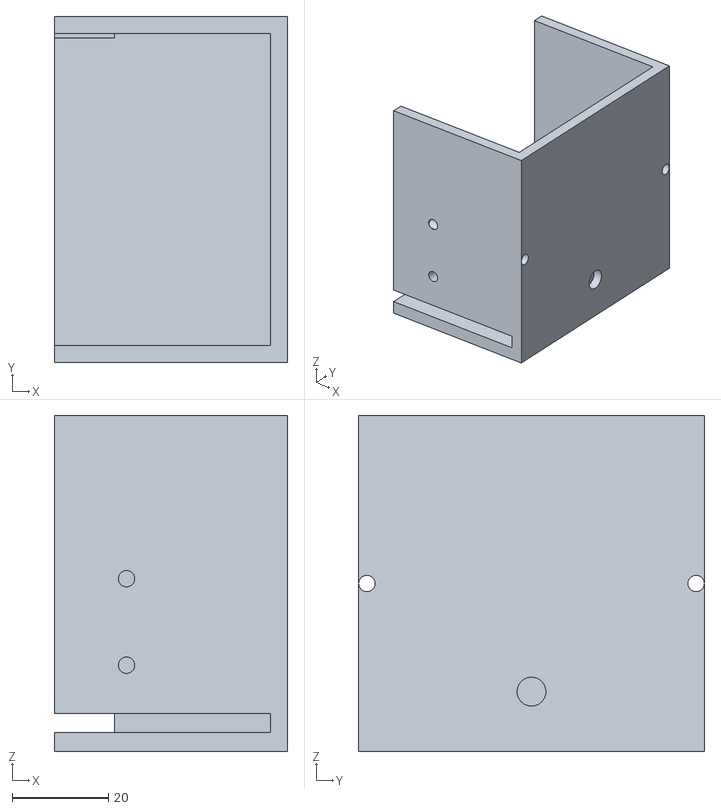
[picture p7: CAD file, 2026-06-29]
design/output/cs2_hopper_right.stl
48.5 x 72.0 x 70.0

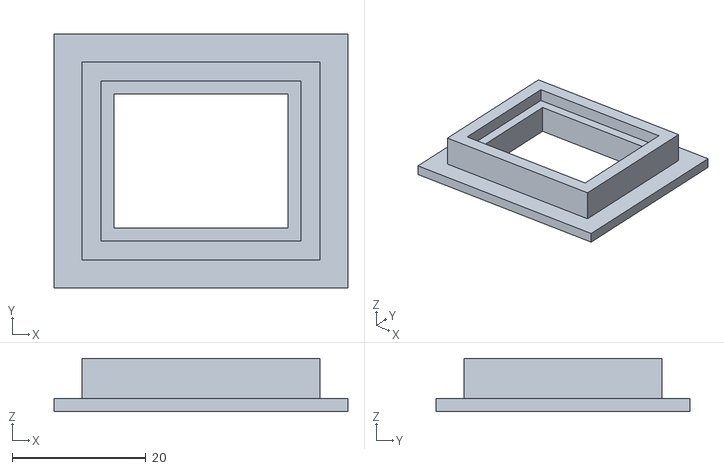
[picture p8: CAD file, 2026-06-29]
design/output/cs2_pol_clip.stl
44.0 x 38.0 x 8.00

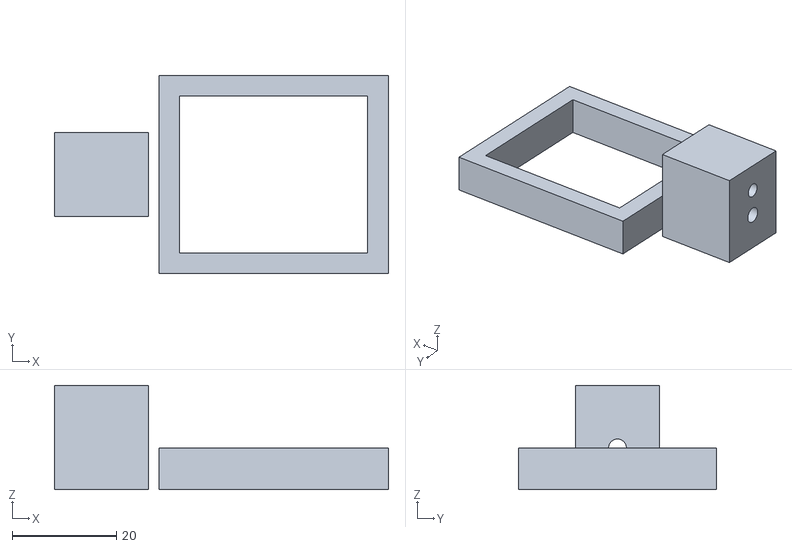
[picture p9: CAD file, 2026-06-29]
design/output/cs2_fit_test.stl
64.0 x 38.0 x 20.0

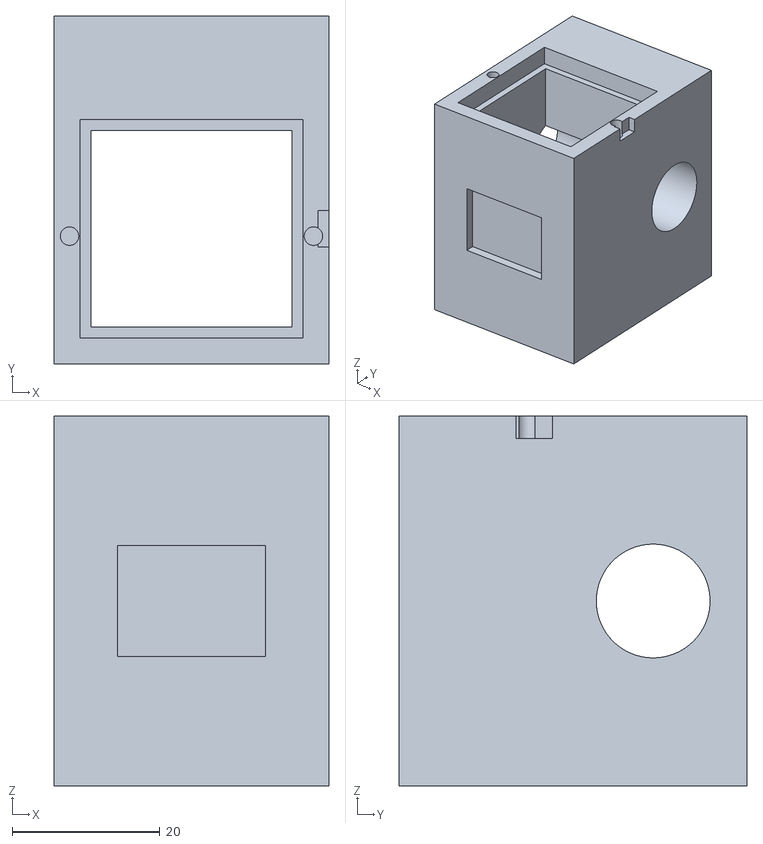
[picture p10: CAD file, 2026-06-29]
design/output/cs2_rack_stand_carriage.stl
37.2 x 47.1 x 50.0

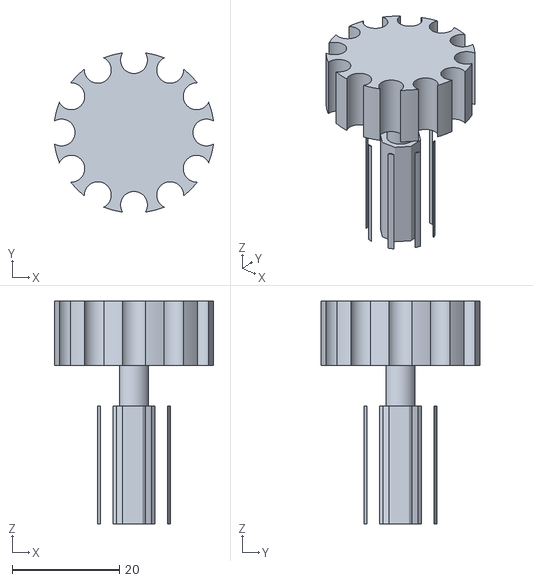
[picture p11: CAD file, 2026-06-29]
design/output/cs2_rack_stand_knob.stl
29.7 x 29.7 x 41.6

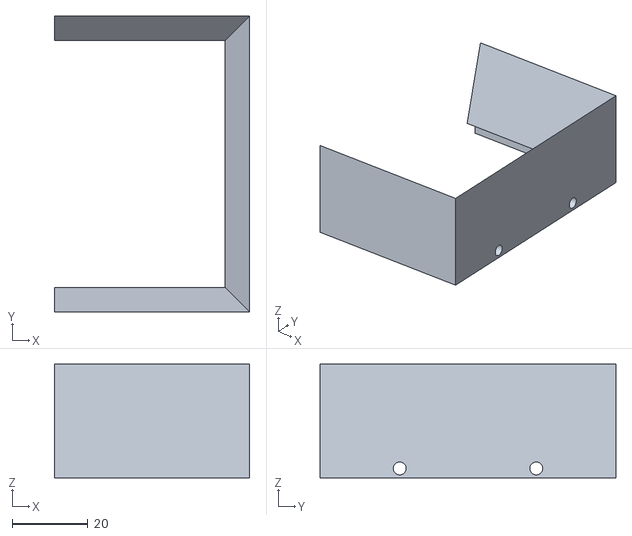
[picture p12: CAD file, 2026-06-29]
design/output/cs2_centering_insert_right.stl
51.5 x 78.0 x 30.0

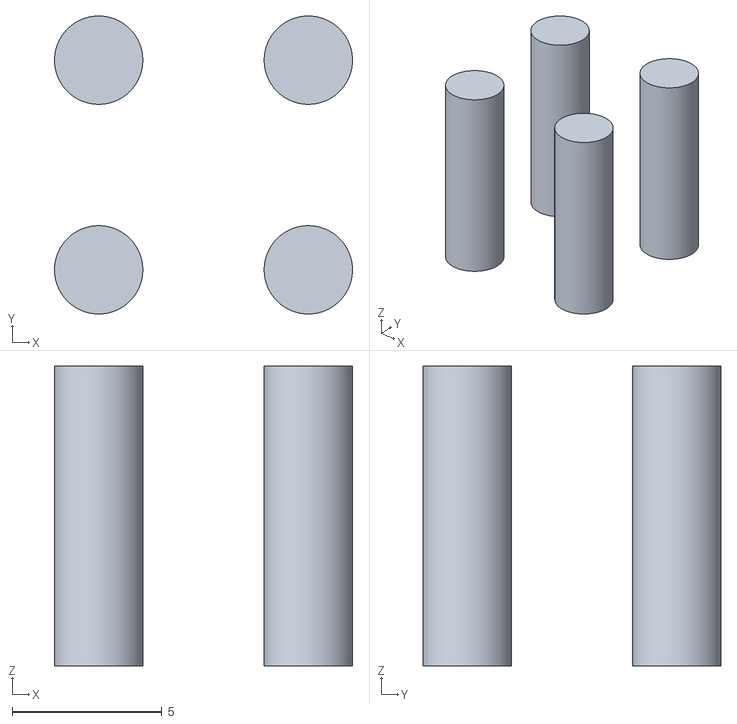
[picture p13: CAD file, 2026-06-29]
design/output/cs2_peg.stl
9.95 x 9.95 x 10.0

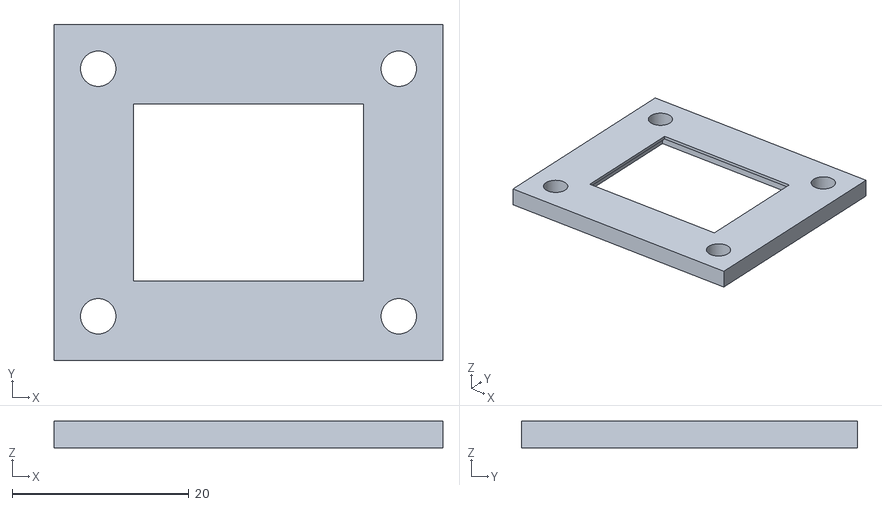
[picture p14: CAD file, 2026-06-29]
design/output/cs2_phone_pol.stl
44.0 x 38.0 x 3.00

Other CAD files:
design/output/cs2_wall_top_right.stl
design/output/cs2_hopper_left.stl
design/output/cs2_motor_bracket.stl
design/output/cs2_separator_body.stl
design/output/cs2_centering_insert_left.stl
design/output/cs2_push_rod.stl
design/output/cs2_rack_stand_fit_test.stl
design/output/cs2_rack_stand_platform.stl
design/output/cs2_roller.stl
design/output/cs2_roller_plate.stl
design/output/cs2_separator_gap_plate.stl
design/output/cs2_wall_bot_left.stl
design/output/cs2_wall_bot_right.stl

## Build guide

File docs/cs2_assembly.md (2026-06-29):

# CS2 Card Scanner — Assembly Guide

## Parts required

| Part | File | Qty | Material | Notes |
|---|---|-----|---|---|
| Hopper left | cs2_hopper_left.stl | 1 | Black PLA | Print upright |
| Hopper right | cs2_hopper_right.stl | 1 | Black PLA | Print upright |
| Wall bot left | cs2_wall_bot_left.stl | 1 | Black PLA | Print upright |
| Wall bot right | cs2_wall_bot_right.stl | 1 | Black PLA | Print upright |
| Wall top left | cs2_wall_top_left.stl | 1 | Black PLA | Print upright |
| Wall top right | cs2_wall_top_right.stl | 1 | Black PLA | Print upright |
| Platform | cs2_platform.stl | 1 | Black PLA | Print flat |
| Alignment peg | cs2_peg.stl | 1 plate | PETG pref. | 4 pegs; use 2 |
| Fit test | cs2_fit_test.stl | 1 | Same PLA | Print FIRST |

**Optional accessories (cross-pol / diffuser):**

| Part | File | Qty | Material |
|---|---|-----|---|
| Aperture polarizer clip | cs2_pol_clip.stl | 1 | White or clear PLA |
| Phone camera polarizer frame | cs2_phone_pol.stl | 1 | White or clear PLA |
| Torch diffuser plate | cs2_diffuser.stl | 1 | **White PLA only** |

## Hardware BOM

| Item | Qty | Spec |
|---|-----|---|
| M3×30 socket-head bolt | 8 | 2 platform-to-wall + 6 wall section joins |
| M3×20 socket-head bolt | 4 | 2 hopper half joins + 2 spare |
| M3 hex nut | 12 | All bolt receivers |
| 3mm alignment peg | 2 | Cut from cs2_peg.stl (10mm long) |
| CA glue (thin) | few drops | Wall-to-hopper bond |

## Step 0 — Print fit test FIRST

Print `cs2_fit_test.stl` before any full parts. Two features:

**Feature A — peg and bolt holes (left block, 18×16×20mm):**
- Thread M3×20 bolt through the 3.4mm hole (X-direction). Must pass freely.
- Push a 3mm peg into the 3.0mm blind hole (Z=14mm). Should seat snug with thumb pressure.
- If peg is too tight: increase `PEG_D` in `cs2_peg.py` by 0.05mm steps; re-export and reprint.
- If bolt binds: increase `BOLT_D` in `cs2_platform.py` / `cs2_wall.py` by 0.05mm; re-export.

**Feature B — pol_clip press-fit ring (right block, 44×38×8mm):**
- Press `cs2_pol_clip.stl` plug (35.6×29.6mm) into the 36×30mm aperture from below.
- Should seat with firm thumb pressure and hold without glue.
- Too tight: increase `PLUG_W` / `PLUG_D` in `cs2_pol_clip.py` by 0.1mm.
- Too loose: decrease by 0.1mm.

## Step 1 — Assemble hopper halves

1. Push one 10mm peg into each of the two seam holes on the left half (front and back walls, Z=17mm).
2. Align right half onto the pegs.
3. Thread M3×20 bolts through the two X-direction bolt holes (Z=25mm). Start nuts finger-tight.
4. Check card slot is flush and square, then tighten bolts.

The assembled hopper is 97×72×50mm. The card slot is 90×65mm; standard 88×63mm cards drop in with 1mm clearance per side.

## Step 2 — Assemble wall column

Wall prints in four sections (two bot + two top, each ≈49.5mm wide). Each pair is joined at the seam.

1. Align bot-left and bot-right at the X seam.
2. Thread M3×30 bolts through the three Z-direction seam holes; add nuts and snug down.
3. Repeat for top-left and top-right.
4. Stack bot section (Z=0..87mm) and top section (Z=87..174mm); thread three M3×30 bolts through the stacking holes; tighten.

The completed wall column is 97×14×174mm.

## Step 3 — Attach wall to hopper

The wall column front face seats against the hopper back face (0.1mm design gap — close enough to be snug in print).

1. Apply thin CA glue to the hopper back face (full width, 97mm).
2. Press the wall front face firmly against the hopper back face.
3. Hold 60 seconds; cure 5 minutes before handling.

The wall bottom rests on the same table surface as the hopper, so Z alignment is automatic.

> **Phase 2 note:** A bolt-down wall flange will replace the CA bond. The current Phase 1 bond is permanent but strong (97mm glue line).

## Step 4 — Mount platform at target height

Choose a bolt-hole height (see height table below). The wall has four sets of bolt holes:

| Bolt hole Z | PLAT_Z | Cam-to-card | Use case |
|---|---|---|---|
| 104mm | 100mm | 104mm | Ultra-close macro |
| 129mm | 125mm | 129mm | **Recommended standard** |
| 154mm | 150mm | 154mm | Wider field of view |
| 169mm | 165mm | 169mm | Near-maximum height |

1. Push the platform back edge (at Y=36mm) flush against the wall front face.
2. Platform Y-bolt holes are at Z=4mm from platform bottom (Y-direction, X=±22mm).
3. Thread M3×30 bolts in through the platform back edge; engage the wall holes.
4. Add M3 nuts on the wall back face; tighten until platform is level.

Platform should be level (use a card as a feeler gauge — it should slide in without binding).

## Step 5 — iPhone 16 Pro placement

The iPhone 16 Pro (71.5×149.6×8.25mm) rests face-down on the platform.

- **Camera protrusion:** The iPhone 16 Pro camera module protrudes 3.9mm from the back. This protrudes into the 36×30mm aperture tunnel (8mm deep). ✓
- **X-centering:** The phone (71.5mm) overhangs the platform (68mm) by 1.75mm each side; gravity centres it in X.
- **Y-positioning:** Slide the phone until you can see the camera lens through the aperture when viewed from below. The aperture is 30mm deep in Y — there is ample margin. Look through the aperture from the card side; the camera lens should be visible.
- **Orientation:** Action-button edge or charging-port edge facing the wall — either works. Confirm camera is visible through aperture before scanning.

## Step 6 — Standard scanning (no accessories)

1. Place card face-up in the hopper slot. Card rests at Z=4mm on the hopper floor.
2. Place iPhone face-down on platform, camera over aperture (Step 5).
3. Open Apple Camera in Photo mode. Pinch to enable macro or use ultra-wide lens.
4. Card is at 104–169mm below the camera (depending on height). Ultra-wide macro range: 20–140mm.
5. The camera app will auto-focus. Take the photo.

Recommended height: **129mm** (PLAT_Z=125mm). At this distance the ultra-wide camera covers a 63×88mm card with ~10% margin each side.

## Step 7 — Torch diffuser (optional, recommended for standard cards)

The `cs2_diffuser.stl` white PLA plate catches the phone torch and scatters it into the hopper, replacing harsh single-point illumination with large-area soft-box fill.

1. Place diffuser flat on platform top (68×75mm plate, 1.5mm thick).
2. Align aperture in diffuser with platform aperture (one correct orientation — notch is asymmetric).
3. Place iPhone on diffuser. Phone now sits 1.5mm higher; negligible focus shift (<1.2% at 125mm).
4. Enable torch in Camera app (or use a separate torch app). The white PLA scatters the light.

**Use diffuser for:** Standard cards, non-foil cards, any card that is not holographic.

## Step 8 — Cross-polarization (optional, for holo/foil cards)

Holographic and foil cards produce specular glare that obscures card detail. Cross-polarization eliminates this.

**What you need:**
- `cs2_pol_clip.stl` (aperture side, installed in platform aperture)
- `cs2_phone_pol.stl` (lens side, held over iPhone camera)
- Two pieces of linear polarizing film: one 30×24mm, one 30×24mm
- Rubber band

**Setup:**
1. Cut two pieces of linear polarizing film to 30×24mm.
2. Insert one film piece into the `cs2_pol_clip` top pocket (film sits in the aperture, camera side).
3. Press `cs2_pol_clip` plug into the platform aperture from below. Flange seats flush on platform bottom.
4. Insert the second film piece into the `cs2_phone_pol` recess.
5. Place `cs2_phone_pol` over the iPhone camera cluster, film touching camera glass. Loop rubber band over iPhone corners to hold in place.
6. **Rotate one film 90°** relative to the other. This is the cross-polarization angle that kills specular reflection.
7. With torch on: glare from holo/foil will disappear; card detail becomes visible.

**Diffuser + cross-pol:** You can use the diffuser plate AND the pol_clip together. Install pol_clip first, then diffuser on top of platform, then phone. Both accessories stack without interference.

## Phase 2 — Motorized card eject (future)

The hopper is pre-provisioned for a motor-driven card eject mechanism. Do not attempt Phase 2 until Phase 1 is fully assembled and tested.

**Parts required (Phase 2):**
- `cs2_roller.stl` — 4× drive rollers (PETG, press-fit on 6mm rod)
- 6mm smooth rod, 100mm long (hardware store — look for "6mm steel rod" or M6 rod)
- N20 gear motor, 6V, 30–60 RPM output (10×12×20mm body)
- `cs2_motor_bracket.stl` — motor mount bracket (**not yet designed**)

**Mechanism:** The roller (8mm OD) sits on the 6mm shaft at z=8mm. Its bottom face is at z=4mm — exactly card floor level. With a 0.8mm card under it, the roller compresses the card by 0.8mm and drives it forward through the 15×4mm exit slot when the motor rotates.

**Roller installation:**
1. Source a 6mm smooth rod, 100–110mm long.
2. Slide two rollers onto the rod at x=−7.5mm and x=+7.5mm (over the exit slot center).
3. Apply a drop of CA glue at each roller bore before pressing home.
4. Feed rod through one hopper end wall shaft hole, through both rollers, through the other shaft hole.
5. Motor couples to one rod end (coupling bracket TBD in Phase 2 design).

## Rebuild STLs

```
# Re-export all CS2 STLs (if constants change after fit test):
py design/cs2_hopper.py    # PART=1 left, PART=2 right
py design/cs2_platform.py  # PART=0
py design/cs2_wall.py      # PART=1..4 (four sections)
py design/cs2_peg.py       # PART=0 print plate
py design/cs2_pol_clip.py  # PART=0
py design/cs2_phone_pol.py # PART=0
py design/cs2_diffuser.py  # PART=0
py design/cs2_roller.py    # PART=1 print plate (Phase 2)
```

Or run all via AgentCAD with the corresponding `.py` script.

## Verification

```
py design/cs2_verify.py
```

Runs 31 checks (dimensions, clearances, alignment, peg positions, bolt holes). All should PASS before printing.

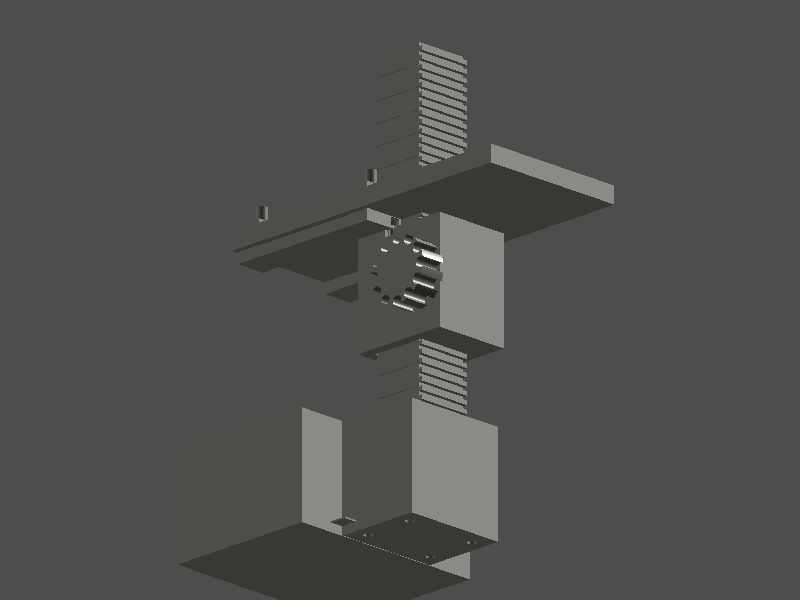
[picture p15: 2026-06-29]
docs/renders/assembly-reverse-shot.png

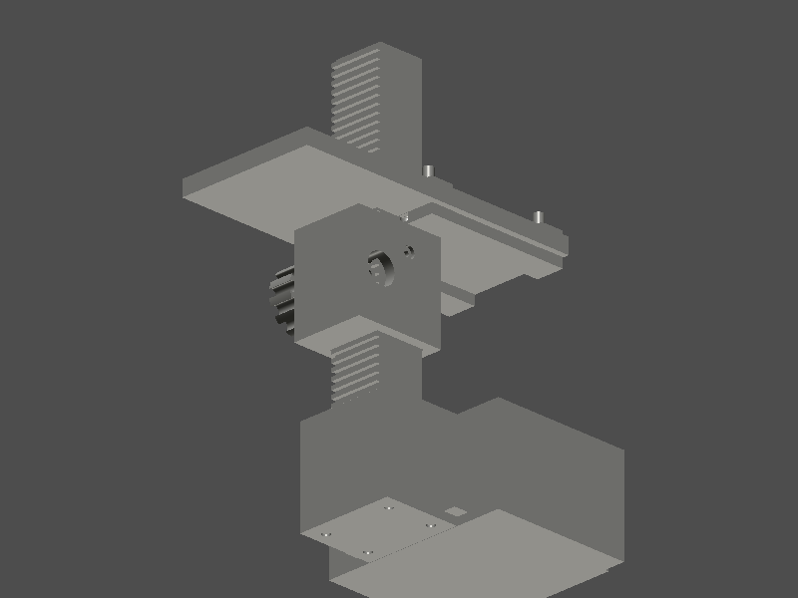
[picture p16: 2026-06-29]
docs/renders/assembly-product-shot.png
